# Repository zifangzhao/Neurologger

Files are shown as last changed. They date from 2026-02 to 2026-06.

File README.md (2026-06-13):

# WILD

**WILD** (Wireless, Interactive, Lightweight Datalogger) is an ultra-lightweight multimodal neurologger for long-term neural and behavioral recording in freely behaving animals. It combines local neural data logging, behavioral sensing, onboard processing, and responsive stimulation in a head-mounted platform designed for naturalistic and multi-animal experiments.

## Documentation

The documentation portal is built with MkDocs Material and is maintained through Markdown files in [`docs/`](docs/).

- [Getting Started](docs/getting-started/index.md)
- [Hardware](docs/hardware/index.md)
- [Software](docs/software/index.md)
- [Analysis](docs/analysis/index.md)
- [Community](docs/contributing.md)

## Platform Scope

- Local microSD electrophysiology recording with BLE-based control, synchronization, status, and low-bandwidth preview
- Closed-loop stimulation through embedded DSP and curated TinyML pipelines
- Current open-source 64-channel workflows, with Neuropixels-compatible and active-probe variants documented separately as research targets
- IMU, ultrasonic audio, camera, and digital event recording
- TinyML inference support through validated release-integrated models
- Long-term recording and multi-animal experiment workflows

## Repository Layout

| Path | Purpose |
| --- | --- |
| [`docs/`](docs/) | MkDocs documentation source |
| [Latest GitHub release](https://github.com/ayalab1/Neurologger/releases/latest) | Prebuilt device release images |
| [`Software/`](Software/) | WILD_console installers |
| [`Code/`](Code/) | MATLAB and Python analysis scripts |
| [`PCB/`](PCB/) | PCB fabrication and assembly files |
| [`3Dprint/`](3Dprint/) | Mechanical parts and CAD files |

## Local Documentation Build

```bash
pip install -r requirements.txt
mkdocs serve
```

The GitHub Pages workflow builds the site with:

```bash
mkdocs build --strict
```

## License

See [LICENSE](LICENSE).

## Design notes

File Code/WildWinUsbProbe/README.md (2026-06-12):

# WILD WinUSB Experiment

This folder is the host-side experiment package for moving the WILD camera preview path away from raw-disk MSC access and onto a WinUSB bulk stream.

## What Is In Here

- `Program.cs`
  - Console tool with:
    - `probe`
    - `paths`
    - `bench-winusb`
    - `bench-msc`
- `WILD_FS_Bridge_WinUSB.inf`
  - Local WinUSB binding package for `USB\VID_0483&PID_572A`
  - Registers the recovered interface GUID `{6C303587-B774-4A8B-8AFF-20557620207A}`
- `Install-WildWinUsbDriver.ps1`
  - Admin install helper for the local INF and a forced device restart
- `Register-WildWinUsbGuid.ps1`
  - Elevated helper that injects `DeviceInterfaceGUIDs` into the live device hardware key and restarts it
- `Reenumerate-WildDevice.ps1`
  - Elevated helper that removes the device and forces a fresh scan after the GUID injection
- `Recover-WildWinUsbGuid.ps1`
  - Read-only SWD helper that dumps the first 512 KB of flash and extracts the WinUSB identity markers

## Current Device Facts

- The shipped desktop app is still on the old MSC/raw-disk path.
  - Installed `WILD_console.exe` still contains `GetPhysicalDriveList`, `CE32_diskIO`, and volume lock/dismount strings.
- The currently attached board is already running a WinUSB firmware image.
  - USB identity: `VID_0483`, `PID_572A`
  - Product string from flash: `WILD USB FS Bridge`
  - Interface string from flash: `WinUSB Stream`
  - WinUSB interface GUID from flash:
    - `{6C303587-B774-4A8B-8AFF-20557620207A}`
- The firmware-side MS OS descriptor block in flash is populated with:
  - `MSFT100`
  - `WINUSB`
  - `DeviceInterfaceGUIDs`
  - the recovered GUID above

## Why The Probe Still Fails On This Machine

Windows currently exposes only the generic USB device interface:

- `\\?\USB#VID_0483&PID_572A#2004BF1A0800#{a5dcbf10-6530-11d2-901f-00c04fb951ed}`

Observed state:

- `winusb.inf` is bound to the device through `USB\MS_COMP_WINUSB`
- the recovered custom GUID is not present under `HKLM\SYSTEM\CurrentControlSet\Control\DeviceClasses`
- `WinUsb_Initialize` on the generic USB interface path fails with `ERROR_INVALID_HANDLE (6)`

So the board is on the WinUSB driver stack, but this host has not exposed an openable user-mode interface for the recovered GUID yet.

## What Was Tried On This Machine

1. Elevated install of `WILD_FS_Bridge_WinUSB.inf`
   - Windows rejected it because the package is unsigned.
2. Elevated write of `DeviceInterfaceGUIDs` directly into:
   - `HKLM\SYSTEM\CurrentControlSet\Enum\USB\VID_0483&PID_572A\2004BF1A0800`
3. Elevated `pnputil /restart-device`
4. Elevated `pnputil /remove-device` followed by `pnputil /scan-devices`

Result after every attempt:

- only the generic `{a5dcbf10-6530-11d2-901f-00c04fb951ed}` USB interface is published
- `WinUsb_Initialize` still fails with `ERROR_INVALID_HANDLE (6)`

The log files for those runs are stored next to the scripts:

- `install-driver.log`
- `register-guid.log`
- `reenumerate-device.log`

## Build

```powershell
dotnet build Code\WildWinUsbProbe\WildWinUsbProbe.csproj -c Release
```

## Probe The Current WinUSB State

```powershell
dotnet Code\WildWinUsbProbe\bin\Release\net8.0-windows\WildWinUsbProbe.dll probe
```

Print candidate interface paths only:

```powershell
dotnet Code\WildWinUsbProbe\bin\Release\net8.0-windows\WildWinUsbProbe.dll paths
```

## Benchmark The WinUSB Path

```powershell
dotnet Code\WildWinUsbProbe\bin\Release\net8.0-windows\WildWinUsbProbe.dll bench-winusb --seconds 5 --read-bytes 16384 --frame-bytes 163840
```

Defaults:

- instance id: `USB\VID_0483&PID_572A\2004BF1A0800`
- start request: `0x40`
- stop request: `0x41`
- status request: `0x42`
- equivalent frame size: `320 * 512 = 163840` bytes

## Benchmark The Legacy MSC Path

The old Python preview loop reads one fixed `163840` byte window from:

- offset `0x1000 * 512 = 0x200000`

Use the console benchmark the same way:

```powershell
dotnet Code\WildWinUsbProbe\bin\Release\net8.0-windows\WildWinUsbProbe.dll bench-msc --path \\.\PhysicalDrive3 --seconds 5
```

## Register The WinUSB Interface On This Host

The local INF is intended to give Windows a stable interface registration for the recovered GUID:

```powershell
powershell -ExecutionPolicy Bypass -File Code\WildWinUsbProbe\Install-WildWinUsbDriver.ps1
```

This requires an elevated shell. If Windows rejects the package because it is unsigned, use it as the template for a signed driver package in the real source tree.

## Recover The GUID Again From SWD

This requires:

- ST-LINK connected
- `STM32CubeProgrammer` installed
- read-only SWD access to the board

```powershell
powershell -ExecutionPolicy Bypass -File Code\WildWinUsbProbe\Recover-WildWinUsbGuid.ps1
```

## Measurement Goal

The intended experiment flow is:

1. Measure the old MSC path with `bench-msc` on an MSC firmware image.
2. Rebind the live WinUSB image with the local interface GUID.
3. Measure the WinUSB bulk path with `bench-winusb`.
4. Compare the equivalent frames per second from both runs.

If step 2 does not succeed on this machine, the remaining gap is host driver registration, not missing firmware-side WinUSB identity data.

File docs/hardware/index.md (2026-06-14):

# Hardware

Hardware documentation covers the WILD device architecture, board fabrication assets, mechanical assembly, power choices, and release-image compatibility for each supported device revision.

<div class="wild-grid two">
  <div class="wild-card">
    <h3>Device Overview</h3>
    <p>Core device specifications, supported modalities, local storage path, wireless control, and closed-loop output paths.</p>
  </div>
  <div class="wild-card">
    <h3>PCB</h3>
    <p>Board packages, fabrication outputs, assembly files, revision notes, and inspection points for manufactured boards.</p>
  </div>
  <div class="wild-card">
    <h3>Mechanical</h3>
    <p>Printable parts, baseplates, camera mounts, enclosure orientation, and fit checks for head-mounted assemblies.</p>
  </div>
  <div class="wild-card">
    <h3>Power</h3>
    <p>Battery and microSD guidance covering boot current, recording runtime, preview load, stimulation, and camera use.</p>
  </div>
  <div class="wild-card">
    <h3>Release Images</h3>
    <p>Validated WILD device images linked to compatible hardware revisions and experiment metadata.</p>
  </div>
</div>

## Hardware Asset Map

| Hardware area | Repository path |
| --- | --- |
| Datalogger PCB | [PCB/Datalogger](https://github.com/ayalab1/Neurologger/tree/main/PCB/Datalogger) |
| Opto module | [PCB/Optomodule](https://github.com/ayalab1/Neurologger/tree/main/PCB/Optomodule) |
| Camera unit | [PCB/CameraUnit](https://github.com/ayalab1/Neurologger/tree/main/PCB/CameraUnit) |
| Mechanical parts | [3Dprint](https://github.com/ayalab1/Neurologger/tree/main/3Dprint) |
| Battery table | [LipoBattery_selection.csv](https://github.com/ayalab1/Neurologger/blob/main/docs/LipoBattery_selection.csv) |
| Prebuilt device images | [Latest GitHub release](https://github.com/ayalab1/Neurologger/releases/latest) |

## Compatibility Record

Document the following for each supported WILD hardware build or dataset:

| Record | Why it matters |
| --- | --- |
| PCB or device revision | Distinguishes connector layout, sensor options, and supported release images. |
| Release tag and image filename | Ties behavior to a reproducible device image. |
| WILD_console version | Defines the export and control tool behavior used in the session. |
| SD card model | Affects boot reliability and long-session write stability. |
| Battery model | Affects boot margin, runtime, and peak-load behavior. |
| Enabled modalities | States whether the session used ephys, IMU, audio, video, stimulation, or external sync. |

## Bring-Up Checklist

Before the first recording on a newly assembled WILD device:

1. Confirm the intended release image and hardware revision match.
2. Confirm battery polarity and boot stability.
3. Confirm microSD insertion and basic discoverability.
4. Confirm BLE connection and synchronization state.
5. Run a short recording, export it, and verify the expected files before any animal session.

## Visual Asset Policy

Public hardware visuals are limited to real WILD device material: device photographs, CAD or EDA exports, microscope images, measured drawings, screenshots from project tools, or hand-authored diagrams derived from measured hardware. AI-generated device photographs or device-like renders are excluded from WILD hardware documentation.

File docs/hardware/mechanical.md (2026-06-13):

# Mechanical

Mechanical files are stored in the repository for baseplates, covers, and camera-related parts.

## Available Files

| Part | Repository path |
| --- | --- |
| Top cover | [WILD_TopCover.STL](https://github.com/ayalab1/Neurologger/blob/main/3Dprint/MouseCase/WILD_TopCover.STL) |
| Baseplate | [WILD_Baseplate.STL](https://github.com/ayalab1/Neurologger/blob/main/3Dprint/MouseCase/WILD_Baseplate.STL) |
| Camera baseplate | [WILD_Baseplate_Camera.STL](https://github.com/ayalab1/Neurologger/blob/main/3Dprint/MouseCase/WILD_Baseplate_Camera.STL) |
| Mouse-case CAD source | [Wild_Case.SLDPRT](https://github.com/ayalab1/Neurologger/blob/main/3Dprint/MouseCase/Wild_Case.SLDPRT) and [WILD_Case.f3d](https://github.com/ayalab1/Neurologger/blob/main/3Dprint/MouseCase/WILD_Case.f3d) |
| Cambridge NeuroTech probe assembly | [WILDAssemblyVertical.stp](https://github.com/ayalab1/Neurologger/blob/main/3Dprint/CambridgeNT_Probe/WILDAssemblyVertical.stp), [WILDAssemblyVertical.f3d](https://github.com/ayalab1/Neurologger/blob/main/3Dprint/CambridgeNT_Probe/WILDAssemblyVertical.f3d), and printable support parts in `3Dprint/CambridgeNT_Probe/` |

## Rendered Model Views

<div class="wild-grid two">
  <figure class="wild-image-frame">
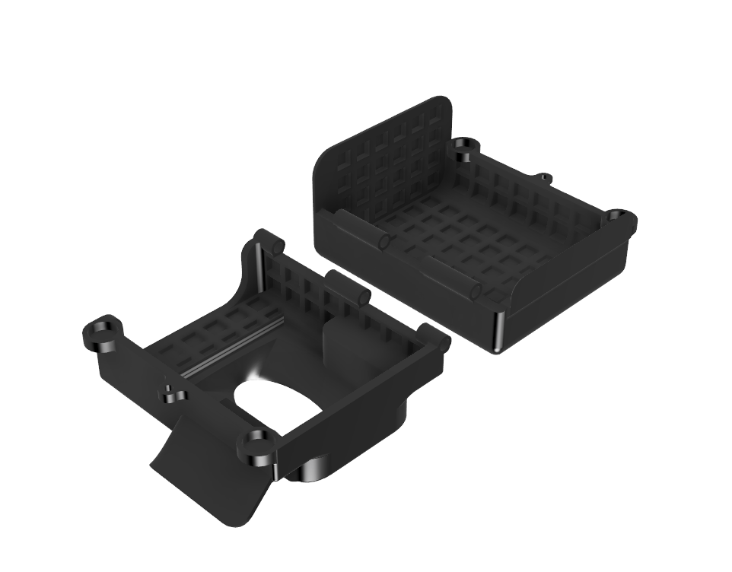
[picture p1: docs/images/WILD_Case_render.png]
Rendered WILD mouse case model with baseplate and cover
    
    <figcaption class="wild-caption">Mouse-case render showing the baseplate and cover geometry for device protection and mounting.</figcaption>
  </figure>
  <figure class="wild-image-frame">
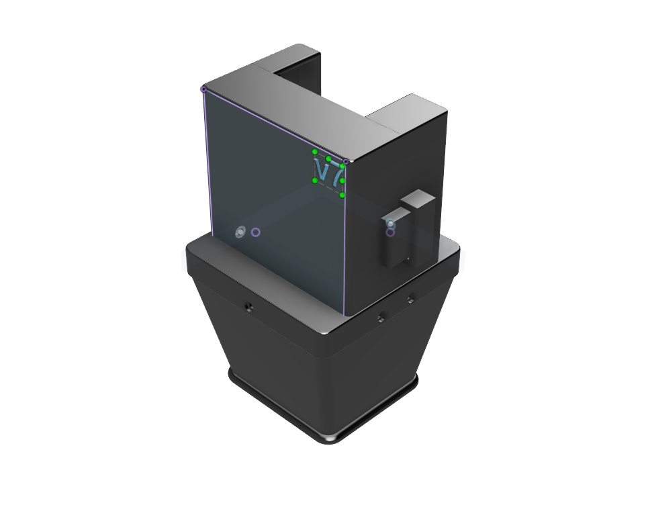
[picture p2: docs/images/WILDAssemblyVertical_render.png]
Rendered vertical WILD assembly for Cambridge NeuroTech probe workflow
    
    <figcaption class="wild-caption">Vertical assembly render for the Cambridge NeuroTech probe workflow, useful for checking model orientation and enclosure clearance.</figcaption>
  </figure>
</div>

## Design Considerations

- Keep cable strain relief and connector access visible in photos.
- Document orientation of the baseplate relative to probes, stimulation leads, and camera modules.
- Include printing material, layer height, support recommendations, and post-processing steps.
- Add animal-specific mounting notes only after local approval and protocol review.

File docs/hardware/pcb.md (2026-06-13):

# PCB

Board packages support ordering, assembly, and inspection for WILD hardware revisions.

## Fabrication Files

| Board | Files |
| --- | --- |
| Datalogger | [Gerbers, drill files, assembly files](https://github.com/ayalab1/Neurologger/tree/main/PCB/Datalogger) |
| Opto module | [Gerbers, drill files, assembly files](https://github.com/ayalab1/Neurologger/tree/main/PCB/Optomodule) |
| Camera unit | [Gerbers, drill files, assembly files](https://github.com/ayalab1/Neurologger/tree/main/PCB/CameraUnit) |

## Manufacturing Notes

- Review PCB stackup, impedance constraints, and connector orientation before ordering.
- Confirm component availability against the assembly files.
- Inspect the microSD socket, battery connector, BLE UART pins, sensor connectors, and stimulation output path after assembly.
- Keep manufacturing revisions tied to compatible release images.

## Assembly Checks

- Confirm top and bottom orientation against the board files.
- Inspect connectors, solder joints, and the microSD socket before power-up.
- Keep the PCB revision with the experiment metadata.
- Match each board revision to a compatible release image.

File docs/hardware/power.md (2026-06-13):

# Power

Power planning is central to WILD experiments because battery selection, microSD choice, recording mode, selected preview signals, stimulation, and camera use all affect runtime.

## Power Architecture

The WILD device conditions the selected battery through a converter and regulator chain before powering analog acquisition, digital control, and peripheral subsystems. Battery choice should therefore follow the validated hardware-revision guidance rather than a single nominal-voltage number.

Boot, microSD writes, camera use, stimulation, and live preview can create different peak-load conditions. Validate the complete experiment mode on the bench before using a battery in an animal session.

## Battery

The WILD device should use a battery approved for the specific hardware revision and experiment mode. Before mounting the device, confirm that the battery can boot the device without voltage sag, start recording, and sustain the planned sensors, preview state, stimulation, or camera load.

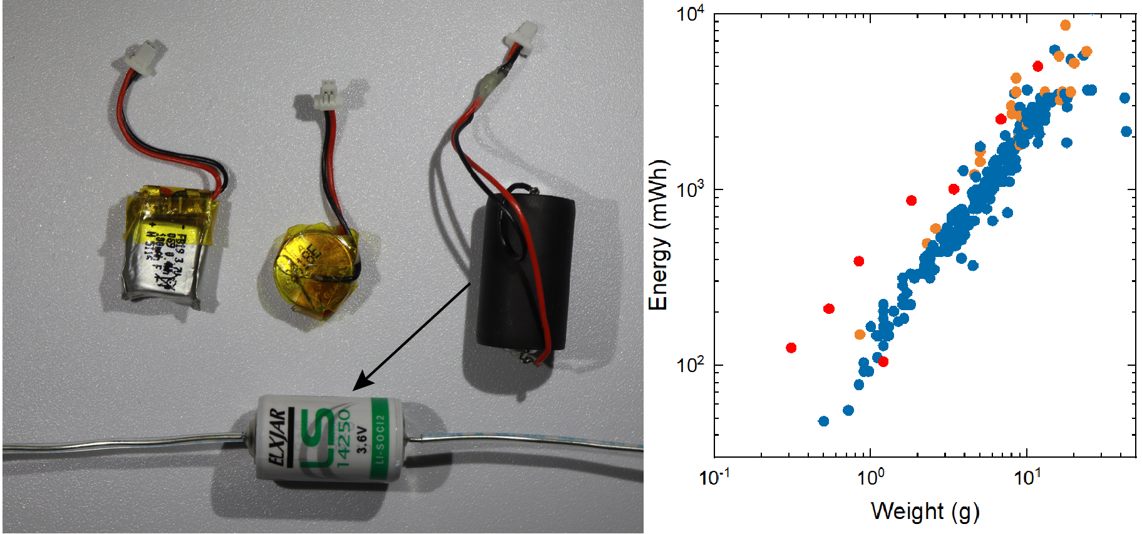
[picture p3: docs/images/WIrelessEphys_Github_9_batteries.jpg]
Battery examples


The [battery selection table](https://github.com/ayalab1/Neurologger/blob/main/docs/LipoBattery_selection.csv) provides baseline capacity and runtime-planning references.

## microSD Power

The microSD card is part of the power and reliability budget. Format cards with WILD_console before recording, and validate the selected card in the same sampling and modality mode planned for the experiment.

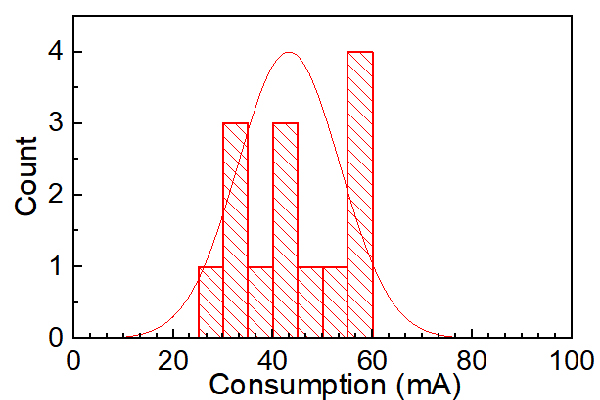
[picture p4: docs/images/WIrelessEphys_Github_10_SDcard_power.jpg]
microSD power comparison


## Runtime Reporting

Runtime depends on sampling rate, active modalities, preview state, stimulation use, microSD card model, battery capacity, and ambient conditions. When reporting a WILD recording mode, include:

- Release image.
- SD card model and format state.
- Battery model and capacity.
- Sampling rate and enabled modalities.
- Preview state.
- Stimulation or TinyML state, if used.
- Session environment, especially for outdoor or long-duration recordings.

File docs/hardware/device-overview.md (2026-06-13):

# Device Overview

The WILD device is a Wireless, Interactive, Lightweight Datalogger: an ultra-lightweight multimodal neurologger for freely behaving animals. The device combines local neural data logging, auxiliary sensing, onboard processing, BLE configuration and status, synchronization, and responsive stimulation.

The WILD device is not a BLE telemetry system. High-bandwidth neural data are recorded locally to microSD; wireless links are used for discovery, configuration, synchronization, status, low-bandwidth preview, and online control commands.

The device is best understood as a head-mounted acquisition and control unit. Neural acquisition, auxiliary sensing, embedded processing, microSD storage, external I/O, and optional stimulation are handled on the device; the host computer or controller supports setup, timing coordination, status review, selected preview, command delivery, and export.

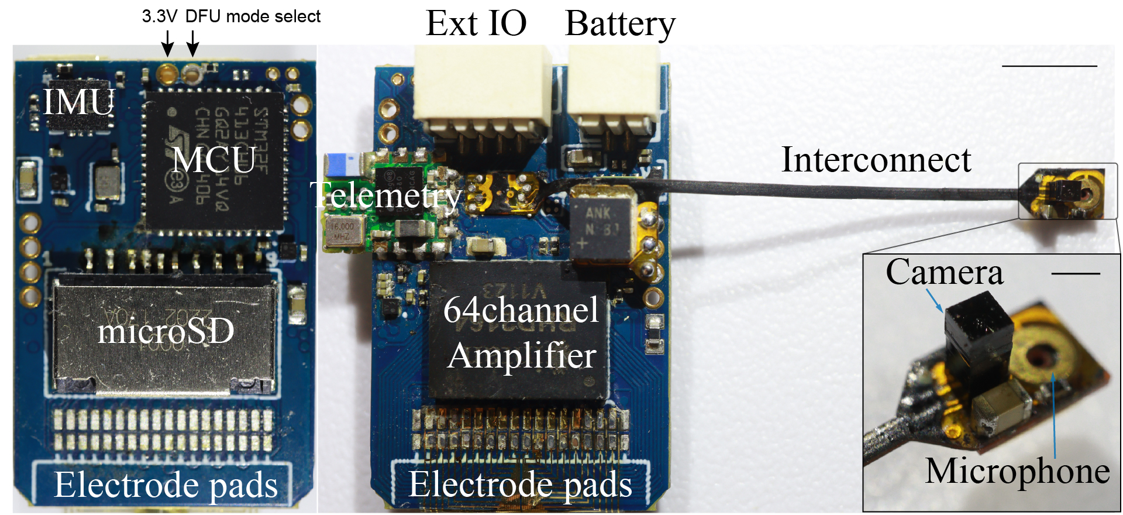
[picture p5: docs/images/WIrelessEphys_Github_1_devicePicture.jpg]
WILD device


## Functional Blocks

```mermaid
flowchart TB
  Probe[Neural probe] --> AFE[Analog front end]
  Sensors[IMU, audio, camera, digital inputs] --> MCU[MCU and embedded DSP]
  AFE --> MCU
  MCU --> SD[microSD storage]
  MCU --> BLE[BLE control, sync, status, preview]
  MCU --> ExtIO[External IO sync and control]
  MCU --> USB[USB setup and bench streaming]
  MCU --> Stim[Stimulation outputs]
  SD --> Analysis[MATLAB, Python, spike sorting]
```

## Device Interfaces

| Interface | Public documentation focus |
| --- | --- |
| Neural input | Standard 64-channel connector workflows and WILD flexible-probe workflows. |
| Local storage | Full-resolution neural, IMU, audio, camera, and event data are recorded to microSD. |
| Wireless control | BLE supports discovery, configuration, synchronization support, status checks, selected preview, and commands. |
| External I/O | Sync and control lines connect WILD devices with cameras, behavior systems, stimulation modules, and multi-device sessions. |
| Bench setup | USB and wired interfaces can support setup and validation workflows when high-bandwidth local monitoring is needed. |

### USB-GPIO Board

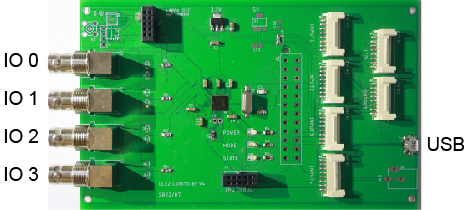
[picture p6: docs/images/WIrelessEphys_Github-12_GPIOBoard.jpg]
USB-GPIO board with IO0 to IO3 and USB interface labels


The USB-GPIO board exposes four external I/O lines and a USB connection for synchronization and validation workflows. Use it when checking camera triggers, behavioral-system events, stimulation-control lines, or multi-device timing before animal recordings.

## Current Public Scope

- The current open-source WILD device release is the 64-channel local-storage neurologger workflow.
- Higher-performance Neuropixels-compatible and active-SPI-probe workflows are separate research and variant targets.
- Multi-device experiments use explicit synchronization workflows rather than BLE timestamps alone.
- Mass is configuration-dependent; report device-only mass, probe or module mass, battery mass, and complete implant mass separately.

## Core Specifications

| Category | Current WILD specification |
| --- | --- |
| Neural channels | 64 |
| Device mass | Approximately 1.5 g for the logger board, configuration-dependent |
| Board dimensions | 23.3 x 15.7 mm |
| MCU | Cortex-M4 class MCU for acquisition, embedded DSP, TinyML scheduling, and device control |
| Power input | Use release-specific approved battery options; internal rails are generated by a converter/regulator chain |
| Sampling rates | 1,250-20,000 Hz |
| ADC resolution | 16-bit electrophysiology and microphone data; 10-bit camera data |
| Storage | microSD, Class 10 or better; low-power endurance cards are preferred |
| Recommended cards | Samsung EVO older orange U1 generation or tested Lexar cards |
| BLE | Control link for discovery, synchronization support, status, selected preview, and low-bandwidth commands |
| IMU | BMX160, up to 500 Hz |
| USV microphone | SPH6611LR5H, approximately 1-80 kHz bandwidth |
| Camera | NanEye-C, 320 x 320 px, 16 FPS, 10-bit |
| Stimulation | Optional two-channel laser-diode stimulation module based on TPS6115x |

## Supported Modalities

- Local neural electrophysiology recording.
- Responsive closed-loop stimulation from onboard detection.
- IMU sensing and sensor fusion.
- Ultrasonic vocalization audio through ADC data.
- Head-mounted camera data through `misc.dat`.
- Digital input and synchronization signals.
- External I/O for synchronization, stimulation control, and integration with behavioral equipment.

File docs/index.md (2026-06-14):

---
hide:
  - navigation
  - toc
---

<section class="wild-hero">
  <div>
    <h1>A wireless modular platform for neuro-behavioral recording and closed-loop manipulation in small animals</h1>
    <p>The Wireless, Interactive, Lightweight Datalogger (WILD) device is an ultra-lightweight multimodal neurologger for local neural data logging, behavioral sensing, onboard processing, and responsive stimulation in freely behaving animals.</p>
    <div class="wild-actions">
      <a class="md-button md-button--primary" href="getting-started/">Get Started</a>
      <a class="md-button" href="hardware/">Hardware</a>
      <a class="md-button" href="software/">Software</a>
      <a class="md-button" href="https://github.com/ayalab1/Neurologger">GitHub</a>
    </div>
    <div class="wild-signal-row">
      <span>64-Channel electrophysiology</span>
      <span>Closed-loop DSP</span>
      <span>9-axis IMU</span>
      <span>USV audio</span>
      <span>Camera</span>
    </div>
  </div>
  <figure class="wild-hero-media">
    WILD wireless modular datalogger device
    <figcaption class="wild-caption">The WILD device integrates local neural recording, behavioral monitoring, real-time embedded processing, microSD storage, and wireless control for naturalistic systems neuroscience experiments.</figcaption>
  </figure>
</section>

<section class="wild-section">
  <div class="wild-grid two">
    <div class="wild-card">
      <h2>Current Public Workflow</h2>
      <p><strong>Stable public scope:</strong> 64-channel local-storage WILD workflow, WILD_console on Windows, validated release images, and post-processing through documented MATLAB and Python scripts.</p>
      <p><strong>Not the current public model:</strong> full-bandwidth BLE telemetry or arbitrary runtime AI-model upload.</p>
    </div>
    <div class="wild-card">
      <h2>Release Record</h2>
      <p>Use the <a href="https://github.com/ayalab1/Neurologger/releases/latest">latest GitHub release</a> and record the exact release tag, release image filename, hardware revision, WILD_console version, SD card, and battery in every experiment note.</p>
    </div>
  </div>

  <div class="wild-grid">
    <div class="wild-card">
      <h3>Run a first recording</h3>
      <p><a href="getting-started/hardware-setup/">Hardware Setup</a> -> <a href="getting-started/data-acquisition/">Data Acquisition</a> -> <a href="getting-started/data-analysis/">Data Analysis</a></p>
    </div>
    <div class="wild-card">
      <h3>Build hardware</h3>
      <p><a href="hardware/pcb/">PCB</a> -> <a href="hardware/mechanical/">Mechanical</a> -> <a href="hardware/power/">Power</a></p>
    </div>
    <div class="wild-card">
      <h3>Analyze data</h3>
      <p><a href="software/data-format/">Data Format</a> -> <a href="analysis/matlab/">MATLAB</a> -> <a href="analysis/python/">Python</a> -> <a href="analysis/spike-sorting/">Spike Sorting</a></p>
    </div>
    <div class="wild-card">
      <h3>Cite or reproduce a result</h3>
      <p><a href="publications/">Publications</a> -> release metadata -> reproducibility notes -> analysis script version</p>
    </div>
  </div>
</section>

<section class="wild-zoom-tour" aria-label="WILD device zoom tour">
  <div class="wild-zoom-stage" aria-live="polite">
    <h2 id="wild-zoom-title">Embedded control at the headstage</h2>
    <p id="wild-zoom-description">The MCU, IMU, and board-level control electronics sit close to the animal, reducing external cabling while keeping timing-sensitive acquisition local.</p>
    <figure class="wild-zoom-frame">
      Real WILD device with labeled functional regions
      <figcaption id="wild-zoom-label">MCU and IMU</figcaption>
    </figure>
  </div>

  <div class="wild-zoom-scroll" aria-hidden="true">

  </div>
</section>

<section class="wild-section">
  <h2>Key Features</h2>
  <p>The WILD device is built around local neural logging, responsive stimulation, embedded processing, multimodal sensing, and long-duration experiments.</p>
  <div class="wild-grid">
    <div class="wild-card">
      <h3>Local Neural Logging</h3>
      <p>High-bandwidth electrophysiology is recorded locally to microSD, while BLE supports setup, synchronization, status, and low-bandwidth preview.</p>
    </div>
    <div class="wild-card">
      <h3>Responsive Stimulation</h3>
      <p>Onboard biomarker detection and behavioral classification can trigger stimulation without requiring continuous wireless data streaming.</p>
    </div>
    <div class="wild-card">
      <h3>TinyML on Edge Devices</h3>
      <p>Curated models run on the MCU through validated release images with RAM, timing, and closed-loop latency reviewed before deployment.</p>
    </div>
    <div class="wild-card">
      <h3>Multimodal Sensing</h3>
      <p>Neural signals, IMU, auxiliary inputs, ultrasonic audio, camera, and digital events.</p>
    </div>
    <div class="wild-card">
      <h3>Long-term Recording</h3>
      <p>Local storage, low power operations, and robust export tools for naturalistic studies.</p>
    </div>
  </div>
</section>

<section class="wild-section">
  <h2>Device Specification Summary</h2>
  <p>Representative WILD device operating modes show how channel count, aggregate sample rate, sensing modules, and onboard processing affect power draw.</p>
  <div class="wild-spec-scroll" role="region" aria-label="WILD device operating mode specification summary" tabindex="0">
    <table class="wild-spec-table">
      <thead>
        <tr>
          <th>Power (mW)</th>
          <th>Channels</th>
          <th>Aggregate samples/s</th>
          <th>Mode</th>
          <th>Weight (g)</th>
          <th>Video</th>
          <th>Audio</th>
          <th>Motion sensor</th>
          <th>Processing</th>
        </tr>
      </thead>
      <tbody>
        <tr><td>0.11</td><td>0</td><td>0</td><td>Sleep</td><td>1.48</td><td>-</td><td>-</td><td>-</td><td>-</td></tr>
        <tr><td>24.42</td><td>8</td><td>4 x 10^4</td><td>Ephys, IMU</td><td>1.48</td><td>-</td><td>-</td><td>Accelerometer, gyroscope, magnetometer</td><td>Spectral power, TinyML</td></tr>
        <tr><td>194.04</td><td>64</td><td>2.6 x 10^6</td><td>Ephys, IMU</td><td>1.48</td><td>-</td><td>-</td><td>Accelerometer, gyroscope, magnetometer</td><td>Spectral power, TinyML</td></tr>
        <tr><td>208.67</td><td>64</td><td>2.92 x 10^6</td><td>Ephys, IMU, audio</td><td>1.48</td><td>-</td><td>160 kHz</td><td>Accelerometer, gyroscope, magnetometer</td><td>Spectral power, TinyML</td></tr>
        <tr><td>245.28</td><td>64</td><td>5.48 x 10^6</td><td>Ephys, IMU, audio, video</td><td>1.48</td><td>320 x 320 px, 16 Hz</td><td>160 kHz</td><td>Accelerometer, gyroscope, magnetometer</td><td>Spectral power, TinyML</td></tr>
      </tbody>
    </table>
  </div>
  <p class="wild-table-note">Values summarize measured or configured device operating modes. Report the exact hardware revision, release image, battery, SD card, enabled modules, and whether aggregate samples/s is summed across recorded streams when comparing runtime across experiments.</p>
</section>

<section class="wild-section">
  <h2>System Overview</h2>
  <p>A typical session moves from the animal-mounted WILD device to local storage, synchronization, and offline analysis.</p>
  <div class="wild-system-panels">
    <div class="wild-flow wild-flow-vertical" aria-label="WILD system overview">
      <div>Animal</div>
      <div>Device</div>
      <div>Sensors</div>
      <div>Storage</div>
      <div>Synchronization</div>
      <div>Analysis</div>
    </div>
    <figure class="wild-image-frame wild-system-figure">
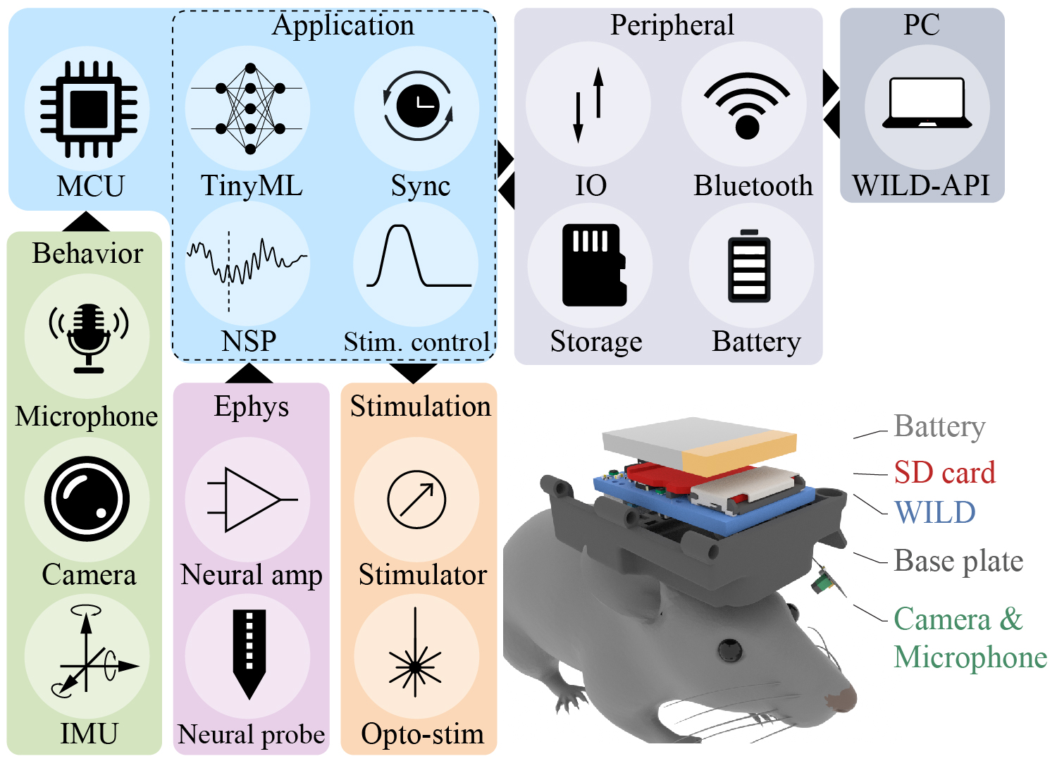
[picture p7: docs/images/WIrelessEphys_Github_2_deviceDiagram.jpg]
WILD system diagram
      
    </figure>
  </div>
</section>

<section class="wild-section">
  <h2>Research Highlights</h2>
  <div class="wild-grid">
    <div class="wild-card">
      <h3>Outdoor recordings</h3>
      <p>Local storage, low-power modes, and wireless control support recordings in large naturalistic environments where tethering is impractical.</p>
    </div>
    <div class="wild-card">
      <h3>Multi-animal experiments</h3>
      <p>Wired sync, BLE calibration, and clock correction workflows coordinate multiple WILD devices and external systems.</p>
    </div>
    <div class="wild-card">
      <h3>Ripple detection</h3>
      <p>DSP filters include ripple-band detection for closed-loop hippocampal experiments.</p>
    </div>
    <div class="wild-card">
      <h3>Theta phase stimulation</h3>
      <p>Hilbert and filter modes support phase-aware online control designs.</p>
    </div>
    <div class="wild-card">
      <h3>Naturalistic behavior</h3>
      <p>IMU, video, USV, and neural data support studies of social interaction, outdoor navigation, and other freely expressed behaviors.</p>
    </div>
    <div class="wild-card">
      <h3>Open hardware iteration</h3>
      <p>The repository contains WILD device hardware files, validated release assets, WILD_console installers, and analysis scripts.</p>
    </div>
  </div>
</section>

<section class="wild-section wild-quickstart">
  <h2>Quick Start</h2>
  <div class="wild-grid two">
    <div class="wild-card wild-step">
      <h3>Hardware setup</h3>
      <p>Connector, battery-polarity, microSD, probe-cabling, sensor-cabling, and release-image checks come before the first recording.</p>
    </div>
    <div class="wild-card wild-step">
      <h3>Data acquisition</h3>
      <p>WILD_console handles BLE connection, synchronization, recording configuration, closed-loop settings, and local logging startup.</p>
    </div>
    <div class="wild-card wild-step">
      <h3>Data analysis</h3>
      <p>Exported recordings are converted into Intan-style files, IMU and camera outputs, and spike-sorting inputs.</p>
    </div>
  </div>
  <p class="wild-table-note">Recommended first success target: complete a short bench recording, export the folder, confirm `amplifier.dat`, `analogin.dat`, `time.dat`, `info.rhd`, and `CE_params.bin`, then open the result with the documented MATLAB or Python workflow.</p>
</section>

<section class="wild-section">
  <h2>Publications and Citation</h2>
  <div class="wild-grid two">
    <div class="wild-card">
      <h3>Platform manuscript</h3>
      <p>The WILD platform manuscript is currently under review.</p>
    </div>
    <div class="wild-card">
      <h3>Repository and release versions</h3>
      <p>Report the hardware revision, release image, WILD_console version, and analysis scripts used for each dataset.</p>
    </div>
  </div>

```bibtex
@article{zhao_wild_neurologger,
  title        = {A wireless modular platform for neuro-behavioral recording and closed-loop manipulation in small animals},
  author       = {Zhao, Zifang and Chang, Hongyu and Paudel, Praveen and Park, Jaehyo and Liu, Can and Aurelio, Maria Q. and Oliva, Azahara and Fernandez-Ruiz, Antonio},
  year         = {2026},
  note         = {Under review}
}
```
</section>

<section class="wild-section">
  <h2>Community</h2>
  <div class="wild-grid">
    <div class="wild-card">
      <h3>GitHub</h3>
      <p><a href="https://github.com/ayalab1/Neurologger">Browse hardware files, release images, WILD_console installers, and analysis scripts.</a></p>
    </div>
    <div class="wild-card">
      <h3>Issues and Pull Requests</h3>
      <p>Use GitHub issues for reproducible bugs or documentation gaps, and pull requests for tested fixes, examples, and compatibility updates.</p>
    </div>
    <div class="wild-card">
      <h3>Contributing</h3>
      <p><a href="contributing/">Issues and pull requests are appropriate for hardware notes, analysis examples, compatibility reports, and documentation improvements.</a></p>
    </div>
  </div>
</section>

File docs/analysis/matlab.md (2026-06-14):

# MATLAB

MATLAB scripts currently provide the main preprocessing path for WILD recordings.

## Scripts

| Script | Purpose |
| --- | --- |
| [`WILD_PreProcess.m`](https://github.com/ayalab1/Neurologger/blob/main/Code/WILD_PreProcess.m) | Generate corrected headers, timing files, and event outputs. |
| [`WILD_PreProcessFolder.m`](https://github.com/ayalab1/Neurologger/blob/main/Code/WILD_PreProcessFolder.m) | Process multiple recordings. |
| [`WILD_ReadHeader.m`](https://github.com/ayalab1/Neurologger/blob/main/Code/WILD_ReadHeader.m) | Read WILD parameter headers. |
| [`WILD_processIMU.m`](https://github.com/ayalab1/Neurologger/blob/main/Code/WILD_processIMU.m) | Process IMU data. |
| [`WILD_scaleIMU.m`](https://github.com/ayalab1/Neurologger/blob/main/Code/WILD_scaleIMU.m) | Scale IMU signals. |
| [`WILD_genIntanHeader.m`](https://github.com/ayalab1/Neurologger/blob/main/Code/WILD_genIntanHeader.m) | Generate Intan-compatible header output. |

## Minimal Workflow

```matlab
cd("C:\code\github\Neurologger\Code");
recording_path = "C:\WILD\example_recording";
WILD_PreProcess(fullfile(recording_path, "amplifier.dat"));
WILD_processIMU(fullfile(recording_path, "analogin.dat"), 100);
```

Adjust paths and sampling assumptions for your recording mode.

## Expected Folder Layout

**Input**

```text
example_recording/
  amplifier.dat
  analogin.dat
  CE_params.bin
  adc.dat           # optional
  misc.dat          # optional
```

**Outputs generated by the public MATLAB path**

```text
example_recording/
  time.dat
  info.rhd
  IMU.mat
  device_event.d01.evt   # if digital events are present
  device_event.s01.evt   # if stimulation-related event files are generated
```

## Known-Good First Pass

1. Run `WILD_PreProcess` on `amplifier.dat`.
2. Confirm that `time.dat` and `info.rhd` appear.
3. Run `WILD_processIMU` on `analogin.dat`.
4. Confirm that `IMU.mat` is generated.
5. Keep the raw export unchanged and write downstream results into a separate analysis copy when reprocessing.

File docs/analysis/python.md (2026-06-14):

# Python

Python utilities cover camera decoding, audio handling, GPIO logging, and validation after SD-card export.

## Scripts

| Script | Purpose |
| --- | --- |
| [`WILD_VideoDecodewAudio.py`](https://github.com/ayalab1/Neurologger/blob/main/Code/WILD_VideoDecodewAudio.py) | Decode camera data with audio handling. |
| [`WILD_VideoDecodewAudio_v2.py`](https://github.com/ayalab1/Neurologger/blob/main/Code/WILD_VideoDecodewAudio_v2.py) | Alternative video decode pipeline. |
| [`WILD_VideoDecodewAudio_folder.py`](https://github.com/ayalab1/Neurologger/blob/main/Code/WILD_VideoDecodewAudio_folder.py) | Batch folder processing. |
| [`WILD_GPIO_Logger.py`](https://github.com/ayalab1/Neurologger/blob/main/Code/WILD_GPIO_Logger.py) | GPIO logging utility. |

## Typical Use

- Decode camera or audio files after exporting a recording folder.
- Batch-process multiple recording folders with the folder variants.
- Log GPIO or serial events during synchronization validation.
- Keep generated media and logs separate from the raw SD export.

## Interactive Commands

Run the Python tools from the repository `Code` folder:

```powershell
cd C:\code\github\Neurologger\Code
python .\WILD_VideoDecodewAudio.py
python .\WILD_VideoDecodewAudio_folder.py
python .\WILD_GPIO_Logger.py
```

- `WILD_VideoDecodewAudio.py` opens a file picker for one `misc.dat` recording and expects the matching `adc.dat` file when audio is present.
- `WILD_VideoDecodewAudio_folder.py` opens a folder picker and recursively processes `misc.dat` files below that root.
- `WILD_GPIO_Logger.py` prompts for a COM port and output folder, then writes a timestamped text log.

## Expected Outputs

```text
example_recording/
  misc.dat
  adc.dat
  adc.wav
  adc.mp3
  misc.mp4
  misc_wAudio.mp4
```

Output names depend on the script path and whether audio is present, but the public decoder workflow writes reviewable media next to the source export by default.

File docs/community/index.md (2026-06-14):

# Community

Community pages collect citation guidance, contribution rules, and support expectations for the public WILD workflow.

## Start Here

<div class="wild-grid two">
  <div class="wild-card">
    <h3>Publications</h3>
    <p>Use the repository citation guidance until the WILD manuscript has a final public citation.</p>
  </div>
  <div class="wild-card">
    <h3>Contributing</h3>
    <p>Report tested hardware revision, release image, software version, and validation notes with every documentation or compatibility update.</p>
  </div>
  <div class="wild-card">
    <h3>Support Path</h3>
    <p>Use GitHub issues and pull requests for reproducible bugs, documentation problems, compatibility reports, and analysis examples.</p>
  </div>
  <div class="wild-card">
    <h3>Visual Policy</h3>
    <p>Public device figures must come from real hardware, CAD, PCB, microscope, or hand-authored source-derived diagrams. AI-generated device imagery is excluded.</p>
  </div>
</div>

## Recommended Metadata for Public Reports

When sharing a method, bug report, example dataset, or compatibility note, include:

- Hardware revision.
- Release image or release tag.
- WILD_console version.
- SD card model.
- Battery model.
- Recording mode and sampling configuration.
- Whether audio, video, IMU, stimulation, or external sync were enabled.

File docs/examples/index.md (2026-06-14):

# Examples

These example workflows summarize common WILD device use cases and the metadata needed to make each experiment reproducible.

## Workflow Index

| Example | Scope | Expected validation |
| --- | --- |
| Basic neural recording | Battery, SD format, BLE connect, recording, export, preprocessing. | `amplifier.dat`, `analogin.dat`, `time.dat`, `info.rhd`, `CE_params.bin`. |
| Closed-loop ripple detection | Filter setup, thresholding, stimulation configuration, validation waveform. | Event files, threshold traces, and stimulation timing review. |
| Theta phase stimulation | Hilbert mode setup, phase logic, stimulation timing, event export. | Phase-locked trigger timing and stimulation event checks. |
| Multi-animal synchronization | Multiple WILD_console instances, start timing, sync line, analysis alignment. | Matched durations, stable offsets, and retained sync events. |
| Outdoor recording | Power planning, SD choice, wireless checks, data integrity checks. | Complete export, no unexpected truncation, and logged power configuration. |
| Camera plus IMU | Camera decode, IMU processing, and behavioral alignment. | Reviewable video output and generated `IMU.mat`. |

## Required Metadata

For each public dataset or protocol, record:

- Goal.
- Hardware revision.
- Release image.
- Software version.
- Required accessories.
- Step-by-step protocol.
- Expected outputs.
- Troubleshooting notes.
- Example data or a small validation file.

## Priority for Expanded Protocol Pages

The highest-value example pages to expand next are:

1. Basic neural recording.
2. Multi-animal synchronization.
3. Closed-loop ripple detection.

These three paths cover the first successful dry run, cross-device timing, and one validated responsive-control workflow.

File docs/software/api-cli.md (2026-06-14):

# Programmatic Workflows

WILD_console and the listed scripts form the supported public interface for acquisition, export, post-processing, and validation.

WILD_console handles BLE discovery, synchronization, configuration, selected preview, and SD-card export. Full-resolution recordings are recovered from local storage rather than streamed continuously over BLE.

An iOS-based WILD controller app is in development for wireless device control and is expected to provide more consistent BLE performance than typical PC BLE adapters. The current stable public export and post-processing workflow remains WILD_console plus the documented MATLAB and Python scripts.

!!! warning "No stable SDK yet"
    The supported public programmable surface is WILD_console plus the documented repository scripts. The project does not currently document a stable general-purpose SDK with a versioned command contract.

## Current Support

| Area | Current operation style | Purpose |
| --- | --- | --- |
| Acquisition | WILD_console | BLE discovery, connection, synchronization, recording setup, selected live preview, closed-loop configuration, and SD-card export. |
| Wireless control | iOS controller app, in development | BLE discovery, connection, synchronization support, status checks, and low-bandwidth commands. |
| Post-processing | MATLAB scripts | Header generation, timing correction, event export, IMU processing, and Intan-compatible output preparation. |
| Camera/audio decoding | Python scripts | Decode `misc.dat` and related audio data into reviewable media outputs. |
| Batch processing | Python and MATLAB scripts | Process folders of recordings after SD export. |
| GPIO logging | Python utility | Log serial/GPIO event data during validation or synchronization tests. |
| Release and model tracking | Release metadata workflow | Record release image, AI model identity, and tool version for reproducibility. |

## Supported Scripted Operations

The current public API surface is organized around these operations:

- Export recording folders from WILD_console.
- Generate corrected `info.rhd` and `time.dat` outputs.
- Convert raw WILD camera/audio data into media files.
- Process IMU channels into calibrated signals.
- Batch-process recording folders.
- Log GPIO or serial synchronization events.
- Preserve software, release-image, and model versions in experiment notes.

## Device Operation Categories

WILD_console and controller workflows expose device operations at a task level. Public documentation should describe these operations by purpose rather than by low-level command ID.

| Category | Typical operations |
| --- | --- |
| Recording control | Set recording parameters, start local recording, stop local recording, and confirm recording state. |
| Preview control | Start or stop selected-channel preview and choose preview channels without treating BLE as the full-resolution data path. |
| DSP and TinyML setup | Load curated DSP or model parameters from a validated release image and record the selected configuration in metadata. |
| Stimulation control | Configure stimulation intensity, thresholds, timing, and manual test triggers when the hardware revision supports stimulation. |
| Time and synchronization | Check the connection, coordinate PC-device time, set device time, and retain external I/O events for experiment-level alignment. |
| Device status | Read parameters, battery state, available storage, device identity, and release-image metadata. |
| Power state | Request sleep or reset only as part of the documented maintenance or field-session workflow. |
| External I/O | Route GPIO and synchronization signals to cameras, behavioral systems, stimulation modules, or additional WILD devices. |

## Tool Metadata

For reproducible use, record the following metadata with tool outputs and example datasets:

- Tool name and version.
- Required operating system and dependencies.
- Input folder or file layout.
- Command or launch procedure used.
- Output files and naming convention.
- Expected runtime and memory requirements.
- Failure modes and troubleshooting notes.
- Validation file or representative dataset, when available.

## SDK Status

WILD_console operations and documented processing scripts are the supported public surface. Script internals remain implementation details unless a workflow is explicitly documented.

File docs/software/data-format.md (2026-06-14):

# Data Format

Each WILD device recording session exports a folder with neural data, auxiliary signals, metadata, and optional camera or audio files.

## Files

| File | Verified public handling | Notes |
| --- | --- |
| `amplifier.dat` | Read by `WILD_PreProcess.m` as channel-interleaved 16-bit neural data. | Sample count is computed as `file_bytes / 2 / Nch`, with `Nch` read from `CE_params.bin`. |
| `analogin.dat` | Used as the auxiliary stream for digital inputs, IMU, and timing-related channels. | Public MATLAB scripts read this stream as 16 channels at 1250 Hz for preprocessing and IMU extraction. |
| `digitalin.dat` | Optional digital-input export artifact. | Not every workflow generates a separate file; public trigger generation currently derives digital events from `analogin.dat`. |
| `adc.dat` | ADC or audio stream used by microphone workflows. | Public Python decode scripts read this file as `uint16` mono audio and generate `.wav` or `.mp3` outputs. |
| `misc.dat` | Raw camera payload stream. | Public Python decode scripts convert this file into reviewable video outputs. |
| `time.dat` | Generated sample-index timeline. | Public MATLAB preprocessing writes `0:(Nsamples-1)` as `int32`. |
| `info.rhd` | Intan-compatible metadata header. | Generated from `CE_params.bin` by `WILD_genIntanHeader.m`. |
| `CE_params.bin` | WILD parameter binary for system and DSP settings. | The public docs refer to this as the WILD parameter binary; MATLAB tools use the filename `CE_params.bin`. |

## Export Decoding

The WILD device records compact local streams on its microSD card. During the current SD-card download workflow, WILD_console decodes the on-device recording into analysis-facing files: neural samples are written to `amplifier.dat`, auxiliary and timing words to `analogin.dat`, ADC or audio streams to `adc.dat`, camera payloads to `misc.dat`, and session parameters to the WILD parameter binary.

The exported folder is therefore the decoded public data interface. Raw device storage blocks are not the expected analysis input; downstream MATLAB and Python tools operate on the downloaded files and generate derived outputs such as `info.rhd`, `time.dat`, event files, media files, IMU outputs, and spike-sorting inputs.

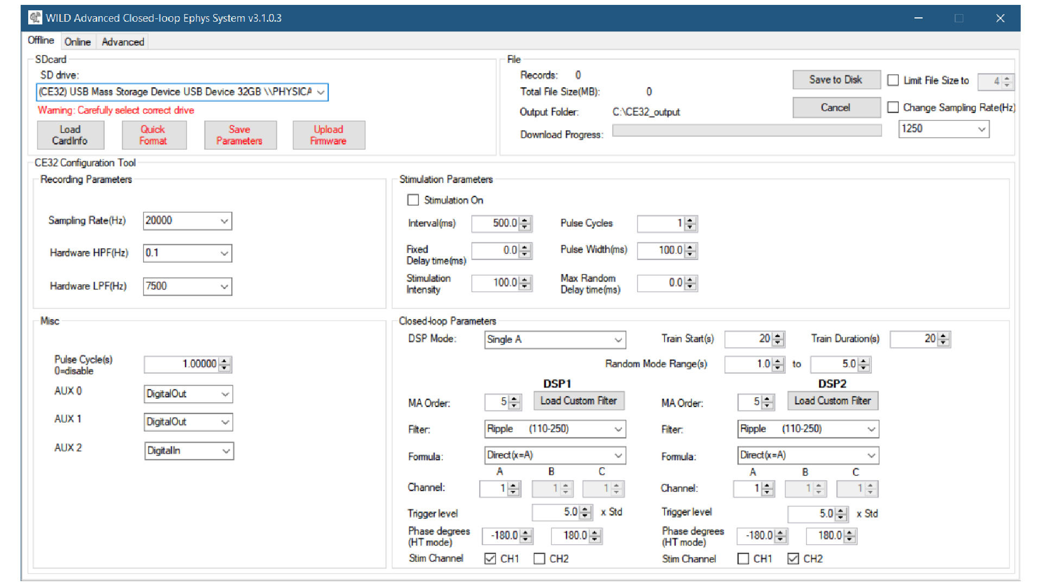
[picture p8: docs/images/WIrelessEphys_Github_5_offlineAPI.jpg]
WILD_console runtime screenshot of the offline export workflow


## Time Synchronization

The WILD device keeps high-bandwidth recordings local while WILD_console provides PC-device coordination over BLE. At connection and recording setup, the console synchronizes device state with the PC session and records timing context with the exported dataset.

Timing metadata should be interpreted as a layered system: device sample counts provide the primary sample timeline, PC-device timing coordination supports session-level alignment, and external I/O or digital events provide the most direct alignment path for external cameras, behavior systems, stimulation hardware, and multi-device sessions.

`time.dat` stores the sample-index timeline used by Intan-style workflows, while the WILD parameter binary preserves device-side recording time, hardware version, release image identity, sampling configuration, and DSP settings. External sync lines and digital inputs in `analogin.dat` or generated event files should be retained with the export whenever the experiment depends on cross-device or behavior alignment.

PC-device time synchronization is useful for session organization, export metadata, and cross-device coordination. It should not be treated as a substitute for hardware sync or digital event channels when the analysis requires high-precision alignment.

## Verified Script Assumptions

The following public assumptions are visible in the repository scripts and should be treated as the current documented behavior unless a release note states otherwise:

- `WILD_PreProcess.m` reads `amplifier.dat` as 16-bit neural samples and uses `CE_params.bin` to determine channel count and sampling rate.
- `time.dat` is written as a monotonically increasing `int32` sample index.
- `WILD_processIMU.m` reads channels `2:10` from `analogin.dat`, assumes a 1250 Hz source rate, and writes `IMU.mat` after resampling to 100 Hz by default.
- `WILD_PreProcess.m` reads channel `1` of `analogin.dat` as a `uint16` digital bitfield and generates `device_event.*.evt` files from its bit transitions.
- `WILD_VideoDecodewAudio.py` reads `adc.dat` as `uint16` audio, converts it to signed audio outputs, and assumes a 160 kHz audio path.
- `WILD_VideoDecodewAudio.py` reads `misc.dat` in `320 * 500` byte frame blocks and writes 320 x 320, 16 Hz decoded video outputs.

Where a file layout depends on a specific release image or modality, report the exact release tag and mode together with the dataset. Do not assume that every export contains every optional modality file.

## Multi-Device and Behavior Alignment

For multi-logger sessions, keep the raw export folder for each device and store merge or sync-estimation outputs alongside the derived files. Useful validation checks include matched `amplifier.dat` duration and file size, stable estimated sample offsets, continuous external TTL or digital events, and no unexpected gaps in camera frames.

Behavior datasets should state whether video, UWB, IMU, and ephys streams are expressed on corrected timestamps. Camera calibration, coordinate transforms, identity curation, and delay correction are part of the dataset metadata, especially for outdoor multi-animal work.

When a behavior pipeline produces files such as `behavior_all.mat`, document whether fields are aligned to corrected timestamps such as `timestamps_corrected` and which correction was used. Post-hoc delay estimation or time warping can help evaluate a session, but it should not replace acquisition-side sync validation.

## Intan-Compatible Layout

WILD exports are arranged to be familiar to users of Intan-style recording folders while preserving WILD-specific metadata for sensors, DSP, stimulation, and camera workflows.

## Best Practice

Keep three folders per experiment:

1. Raw SD export.
2. Converted analysis copy.
3. Downstream results from spike sorting, behavior alignment, or machine-learning analysis.

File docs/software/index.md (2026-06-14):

# Software

Software documentation covers how to connect to the WILD device, configure recordings in WILD_console, export data from the device microSD card, and process recordings for analysis.

## Software Components

<div class="wild-grid two">
  <div class="wild-card">
    <h3>WILD_console</h3>
    <p>Windows GUI for connecting to the WILD device over BLE, synchronizing the session, setting up recordings, previewing selected signals, configuring closed-loop behavior, and exporting SD-card data.</p>
  </div>
  <div class="wild-card">
    <h3>iOS controller</h3>
    <p>In-development app for WILD device discovery, BLE connection, synchronization support, status checks, and low-bandwidth control, with more consistent BLE performance expected than typical PC adapters.</p>
  </div>
  <div class="wild-card">
    <h3>Artificial Intelligence</h3>
    <p>Curated embedded models for validated closed-loop releases, with generic model loading not yet part of the stable workflow.</p>
  </div>
  <div class="wild-card">
    <h3>Programmatic workflows</h3>
    <p>Documented operations for data export, batch post-processing, video/audio decoding, GPIO logging, and validation utilities.</p>
  </div>
  <div class="wild-card">
    <h3>Analysis scripts</h3>
    <p>MATLAB and Python scripts for headers, timing, IMU processing, video decoding, and downstream analysis.</p>
  </div>
</div>

## Install

Download WILD_console from the [latest GitHub release](https://github.com/ayalab1/Neurologger/releases/latest). The link always opens the newest published WILD release.

## Public Workflow Boundary

The current public software path is:

1. Connect and record with WILD_console.
2. Export from the device microSD card.
3. Run documented MATLAB or Python post-processing.

The public documentation does not treat BLE as a continuous high-bandwidth acquisition path, and it does not promise a stable general-purpose SDK yet.

## Wireless Control

WILD_console remains the stable public control and export workflow. The iOS-based controller app is being developed as a lighter wireless-control path for BLE discovery, connection, synchronization support, status checks, and low-bandwidth commands. The iOS workflow is expected to perform better than PC BLE in many setups because it avoids variability across Windows Bluetooth adapters and drivers.

Full-resolution WILD recordings remain local to the device microSD card and are exported after the session.

## Requirements

- Windows 10 or later.
- .NET Framework 4.8 for the current GUI.
- Bluetooth 4.0 or later.
- Administrator privileges for some SD formatting workflows.

## Optional Runtime Files

- `dll_upfirdn.dll` for resampling.
- WILD BLE backend DLL for BLE support in older installer layouts.
- `ffmpeg.exe` for some camera processing workflows.

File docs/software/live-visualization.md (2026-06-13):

# Live Visualization

WILD_console includes a real-time display for previewing selected neural and auxiliary signals during recording.

Live view supports selected previews, status checks, and closed-loop monitoring. Full-resolution recordings are written locally to the device microSD card.

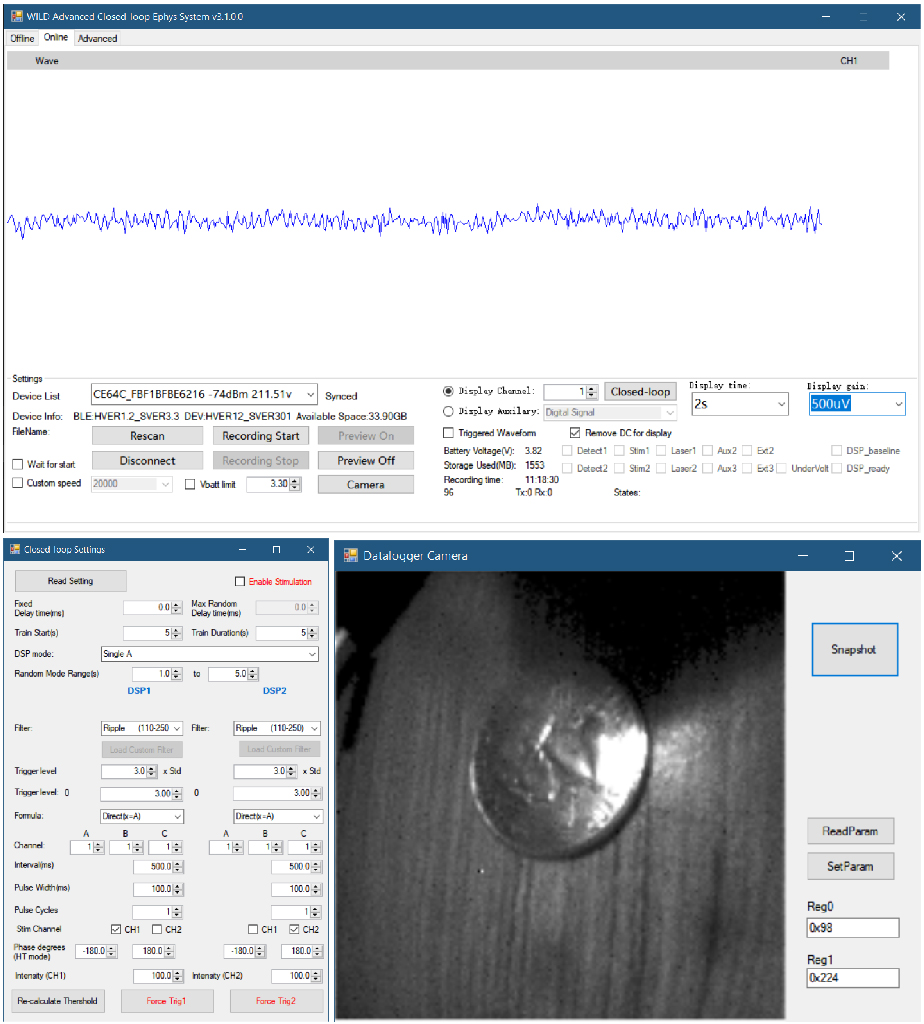
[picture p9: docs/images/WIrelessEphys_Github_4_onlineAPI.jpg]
WILD_console runtime screenshot with live preview and camera windows


## Camera Imaging Profile

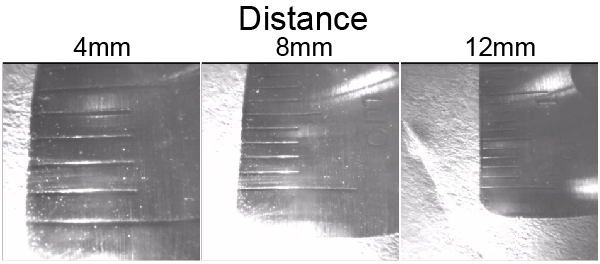
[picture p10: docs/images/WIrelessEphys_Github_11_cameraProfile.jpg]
Camera imaging profile at 4 mm, 8 mm, and 12 mm working distances


Use the camera imaging profile during bench setup to choose the working distance and focus range before mounting the camera module. Confirm the expected target distance with live preview before treating camera data as part of the experiment record.

## Display Controls

- Select neural preview channels.
- Select auxiliary signals from IMU and DSP outputs.
- Adjust display length.
- Adjust display gain.
- Show threshold overlays when closed-loop channels are selected.
- Monitor internal state, stimulation triggers, DSP state, and TinyML state messages.

## Power and Bandwidth

Live preview consumes device power and BLE bandwidth. Disable preview when the experiment prioritizes maximum runtime over live monitoring, and recover the full dataset from microSD after the session.

## Status Checks

- Confirm connection and TX/RX counters after BLE discovery.
- Confirm synchronization before starting a recording.
- Confirm recording state before handling the animal.
- Confirm export completion after removing the microSD card.
- Treat SD, BLE, low-battery, and release-image mismatch messages as session blockers until resolved.

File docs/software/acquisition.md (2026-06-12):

# Acquisition

The acquisition workflow starts by connecting to a WILD device in WILD_console and ends with exported recording folders from the device microSD card.

The WILD device records high-bandwidth neural and multimodal data locally. BLE is used for discovery, synchronization, configuration, status, selected preview, and control commands rather than continuous full-bandwidth data streaming.

WILD_console is the stable public control path today. An iOS-based WILD controller app is in development and is expected to provide more consistent BLE discovery, connection, and low-bandwidth control performance than typical PC BLE adapters. The iOS app is a controller path; full-resolution recordings remain stored on the device microSD card.

## Wireless Connection Model

The WILD device can be connected for discovery, synchronization support, parameter review, selected preview, and command delivery. After setup and timing coordination, local recording does not depend on continuous full-bandwidth wireless streaming because the device writes the full dataset to microSD.

For multi-device sessions, keep continuous BLE connected only for devices that need live preview or online commands. Devices that only need local logging can be configured and synchronized first, then managed with the planned start, stop, external I/O, and export workflow.

## Routine Operation Map

Most first-session work uses four button groups:

| Stage | Main UI area | Primary click |
| --- | --- | --- |
| Discover and connect | Online tab, Device List | <span class="wild-button-label">Rescan</span>, select the WILD device, then <span class="wild-button-label primary">Connect</span> |
| Start recording | Online tab, recording controls | <span class="wild-button-label primary">Recording Start</span> |
| Stop recording | Online tab, recording controls | <span class="wild-button-label">Recording Stop</span> |
| Export data | Offline tab, File panel | <span class="wild-button-label primary">Save to Disk</span> |

Closed-loop settings, camera controls, stimulation parameters, GPIO options, and advanced panels are optional experiment-specific controls. They are easier to configure after the basic connect-record-export path is working.

WILD_console runtime screenshot of the offline export workflow

## Typical Session

1. Start WILD_console.
2. Scan for the WILD device.
3. Connect over BLE.
4. Read current parameters and change experiment-specific settings only when needed.
5. Configure sampling, closed-loop, camera, stimulation, and GPIO options as needed.
6. Start local recording.
7. Monitor selected preview and state signals.
8. Stop recording.
9. Export data from the SD card.
10. Check duration, file size, representative channels, and sync markers before treating the session as complete.

## Multi-Device Sessions

Use one validated release set across all WILD devices. Assign the intended master/follower roles before the session, and keep the same wiring and start order used in the dry run.

For camera workflows, test the external TTL or camera sync path during a short continuous run and confirm that frames, event pulses, and recording files stay aligned before using the setup with animals.

After export, compare recording durations, file sizes, and sample counts across devices. A successful merge should show stable offsets across the recording; jumps, drifting offsets, or one logger ending early should be investigated before the data are treated as synchronized.

## Exported Files

The exported folder can include:

- `amplifier.dat`.
- `analogin.dat`.
- `digitalin.dat`.
- `adc.dat`.
- `misc.dat`.
- `supply.dat`.
- `time.dat`.
- `info.rhd`.
- WILD parameter binary.

See [Data Format](data-format.md) for field descriptions.

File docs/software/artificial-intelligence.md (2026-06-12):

# Artificial Intelligence

The WILD device supports onboard biomarker detection and behavioral classification for responsive stimulation.

Current WILD device releases are intentionally conservative: AI models are curated into validated release images and reviewed for RAM use, compute timing, sampling schedules, and closed-loop latency.

## Current Model Integration

Current AI support uses validated, experiment-specific models rather than arbitrary runtime uploads.

- Models are distributed as part of validated release images.
- RAM use is curated before deployment.
- Inference timing is checked against acquisition, storage, BLE, and DSP tasks.
- Model output is integrated with device state reporting and closed-loop logic.
- Release image and model identity are recorded with each experiment.

This approach keeps timing behavior predictable on resource-constrained embedded hardware.

## Generic Model Support

Generic model loading is not part of the stable public workflow yet. Current releases prioritize predictable timing, memory use, and closed-loop behavior.

Closed-loop model releases define:

- Accepted model format and quantization requirements.
- Maximum model size and tensor arena limits.
- Input and output tensor conventions.
- Inference scheduling relative to acquisition and DSP.
- Validation procedure before animal experiments.
- How model version, release image, and experiment metadata are recorded.

!!! warning "Deployment discipline"
    Embedded AI models are part of the validated device release. A model that passes desktop inference tests may still be unsafe for closed-loop use if RAM pressure or inference timing affects acquisition, storage, or stimulation behavior.

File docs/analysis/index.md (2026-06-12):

# Analysis

Use these pages to convert WILD exports into analysis-ready files, preserve timing metadata, and prepare datasets for MATLAB, Python, and spike-sorting workflows.

## Entry Points

<div class="wild-grid">
  <div class="wild-card">
    <h3>Python</h3>
    <p>Camera decoding, video/audio handling, GPIO logging, and pipeline integration scripts.</p>
  </div>
  <div class="wild-card">
    <h3>MATLAB</h3>
    <p>Header generation, preprocessing, IMU processing, and compatibility with existing lab scripts.</p>
  </div>
  <div class="wild-card">
    <h3>Spike Sorting</h3>
    <p>Export recordings into layouts usable by common spike sorting pipelines.</p>
  </div>
</div>

## Reproducibility Checklist

- Record release image filename.
- Record WILD_console version.
- Preserve raw export folder.
- Preserve the WILD parameter binary.
- Record probe, channel map, sampling rate, and stimulation configuration.
- Track post-processing script version or commit hash.

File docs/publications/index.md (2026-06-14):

# Publications

Publication notes collect the current WILD citation status and the release metadata needed for reproducible methods reporting.

## Platform Manuscript

The WILD platform manuscript is currently under review. Cite the manuscript once the final public citation is available. For repository-based methods descriptions, include the WILD hardware revision, release image, WILD_console version, and analysis-script version used in the work.

```bibtex
@article{zhao_wild_neurologger,
  title        = {A wireless modular platform for neuro-behavioral recording and closed-loop manipulation in small animals},
  author       = {Zhao, Zifang and Chang, Hongyu and Paudel, Praveen and Park, Jaehyo and Liu, Can and Aurelio, Maria Q. and Oliva, Azahara and Fernandez-Ruiz, Antonio},
  year         = {2026},
  note         = {Under review}
}
```

## Repository Citation

When citing a specific software or hardware release, include the GitHub repository URL and the exact release image, software version, and hardware revision used.

Repository: [https://github.com/ayalab1/Neurologger](https://github.com/ayalab1/Neurologger)

## How to Cite Before Publication

Until the platform manuscript has a final public citation, cite the repository and the exact release context used in the work:

- Repository URL.
- Release tag.
- Release image filename.
- Hardware revision.
- WILD_console version.
- Analysis script version or commit hash, when applicable.

The repository now includes a root `CITATION.cff` file for software-style citation metadata.

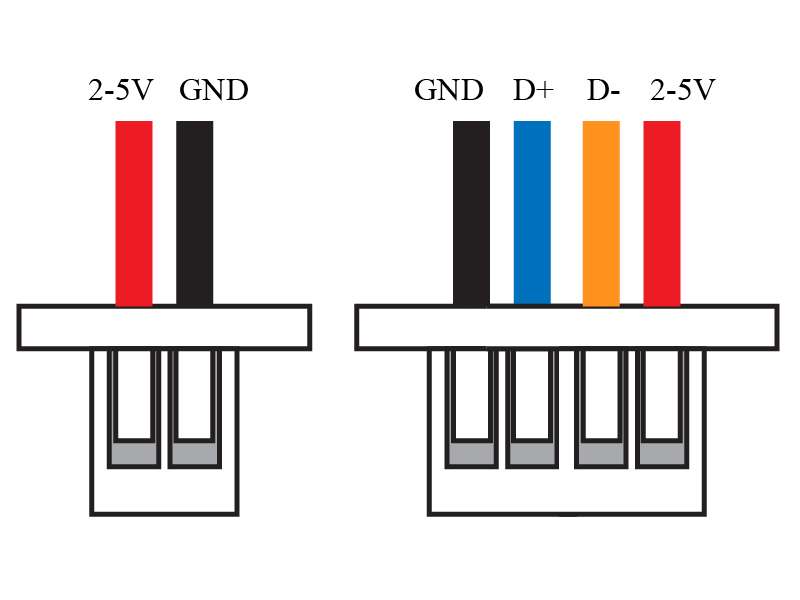
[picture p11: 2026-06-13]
docs/images/WIrelessEphys_Github_6_Connectors.jpg

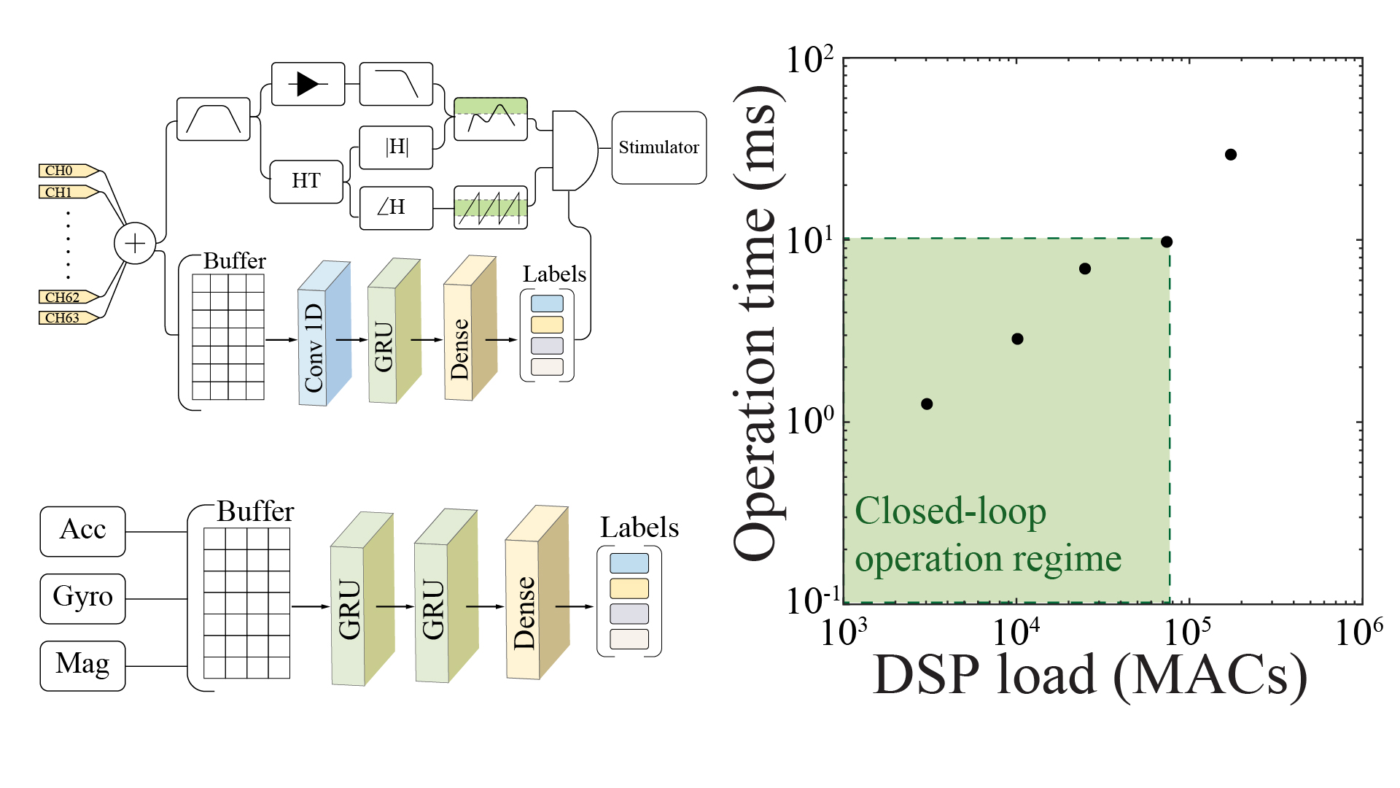
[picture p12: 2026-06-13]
docs/images/WIrelessEphys_Github_7_TinyML.jpg

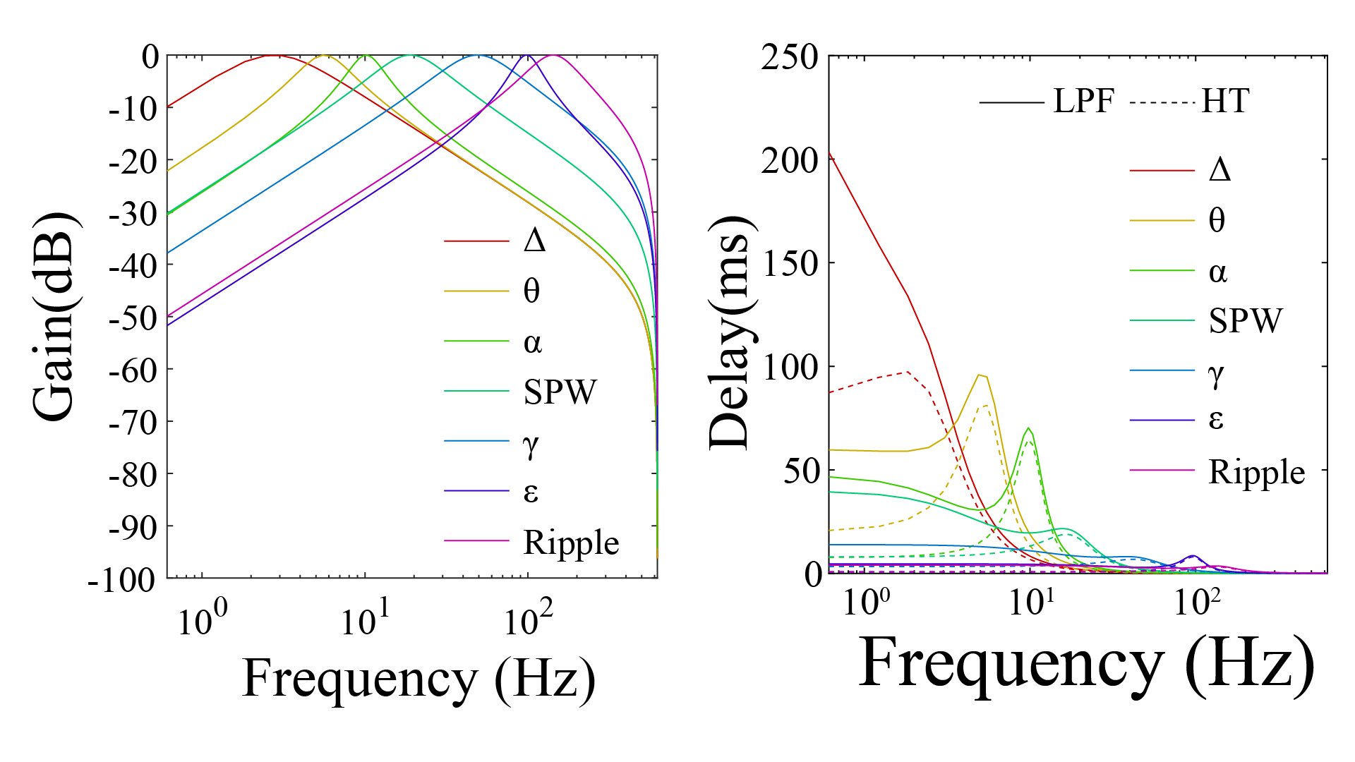
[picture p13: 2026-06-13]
docs/images/WIrelessEphys_Github_3_filterParams.jpg

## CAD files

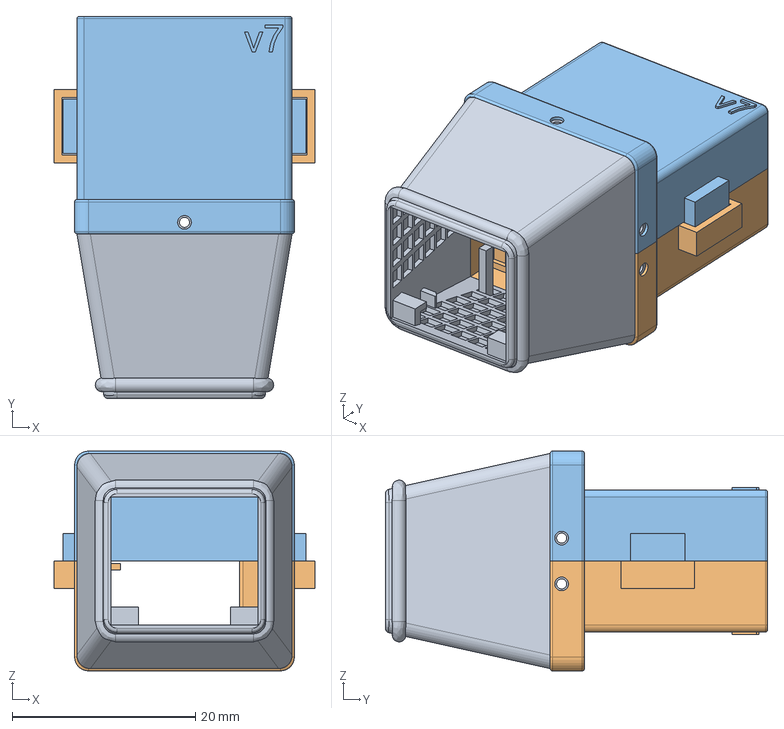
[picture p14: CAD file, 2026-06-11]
3Dprint/CambridgeNT_Probe/WILDAssemblyVertical.stp
28.5 x 41.8 x 24.0 mm
Walls

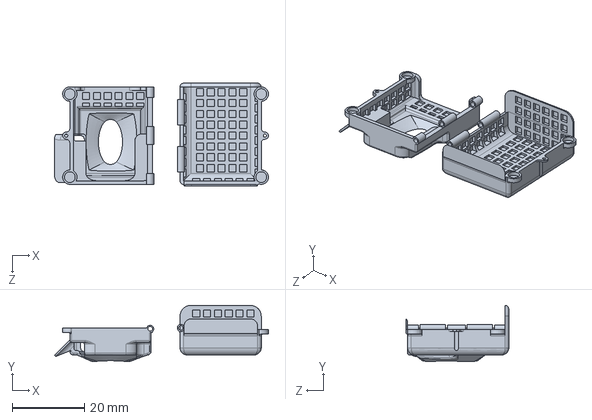
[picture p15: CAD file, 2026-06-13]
3Dprint/MouseCase/Wild_Case.SLDPRT
59.2 x 15.6 x 28.4 mm

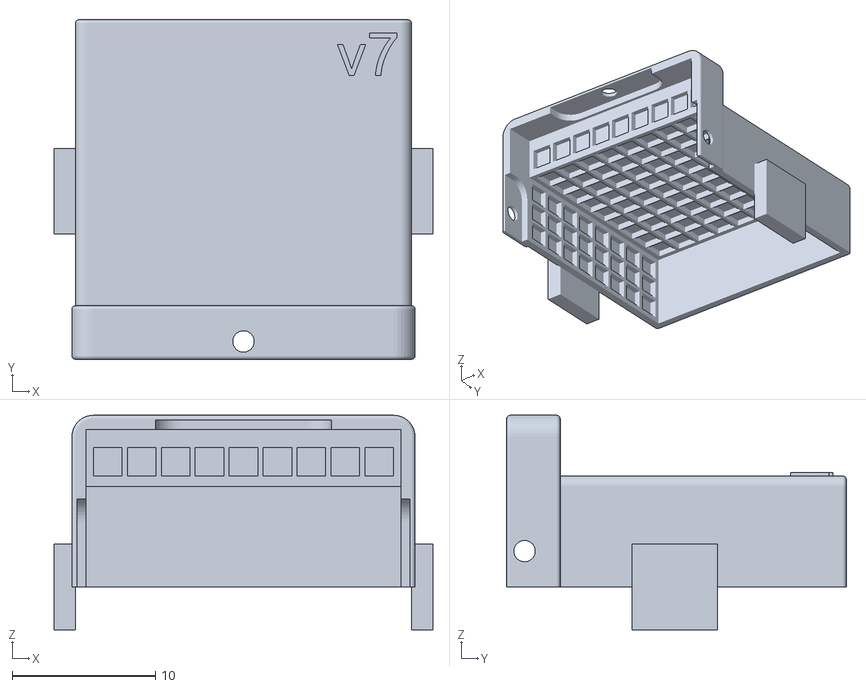
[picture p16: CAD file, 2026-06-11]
3Dprint/CambridgeNT_Probe/Left_v7.stl
26.5 x 23.8 x 15.0

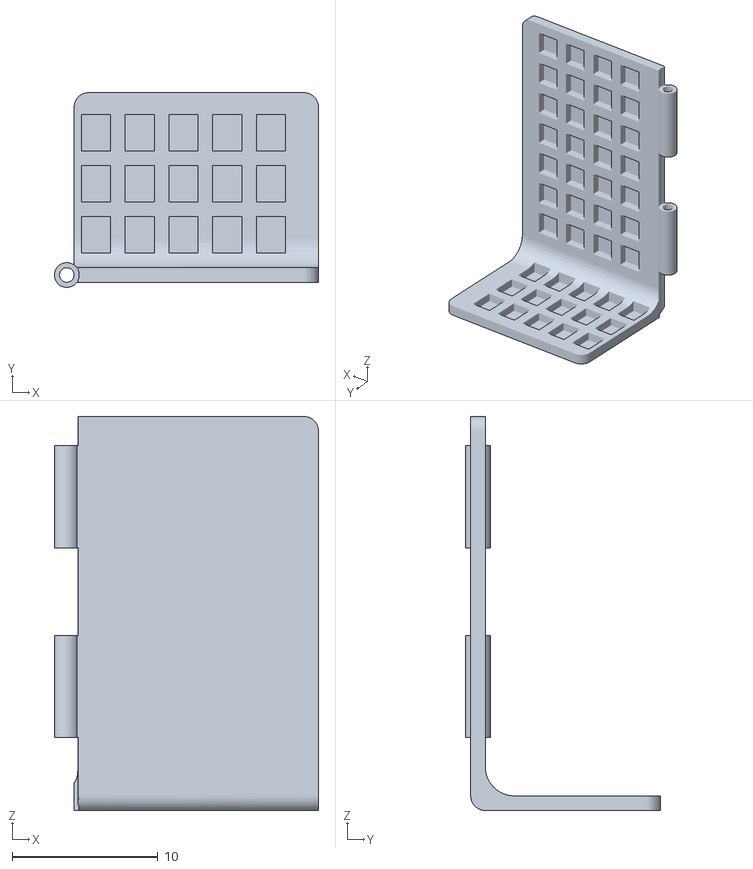
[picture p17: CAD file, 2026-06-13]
3Dprint/MouseCase/WILD_TopCover.STL
18.1 x 13.3 x 27.0

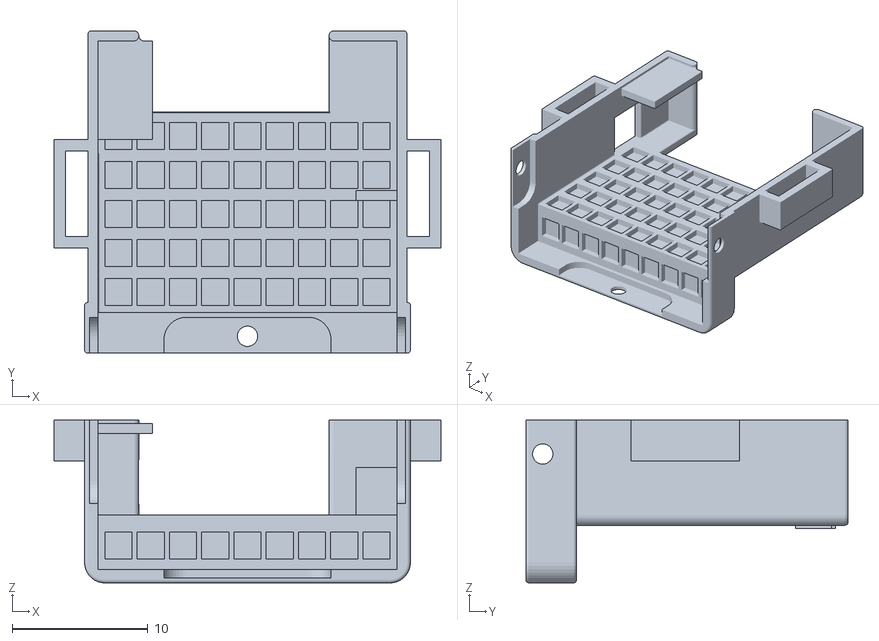
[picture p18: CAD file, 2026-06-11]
3Dprint/CambridgeNT_Probe/Right_v7.stl
28.5 x 23.8 x 12.0

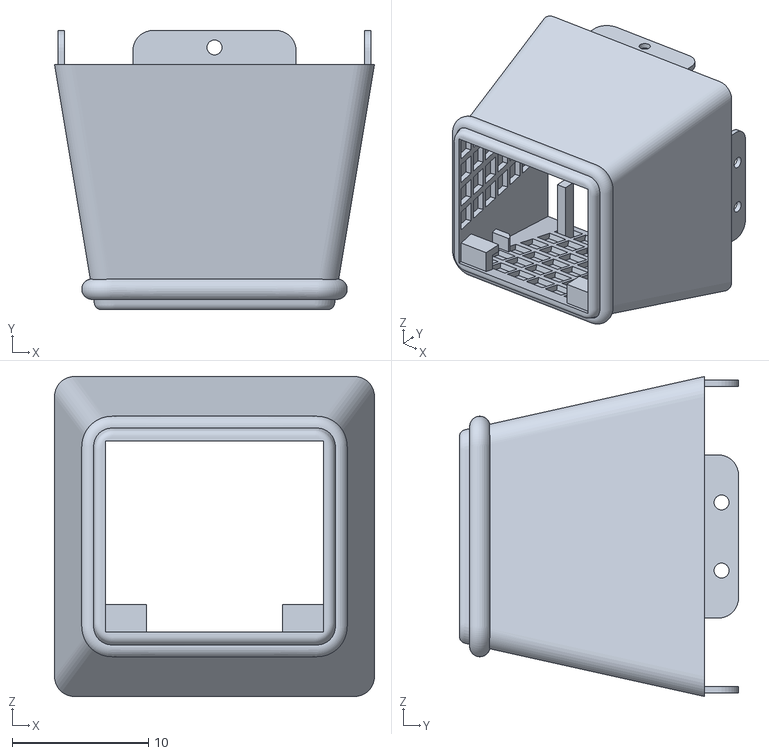
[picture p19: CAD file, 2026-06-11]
3Dprint/CambridgeNT_Probe/Cone_v7.stl
23.5 x 20.5 x 23.5

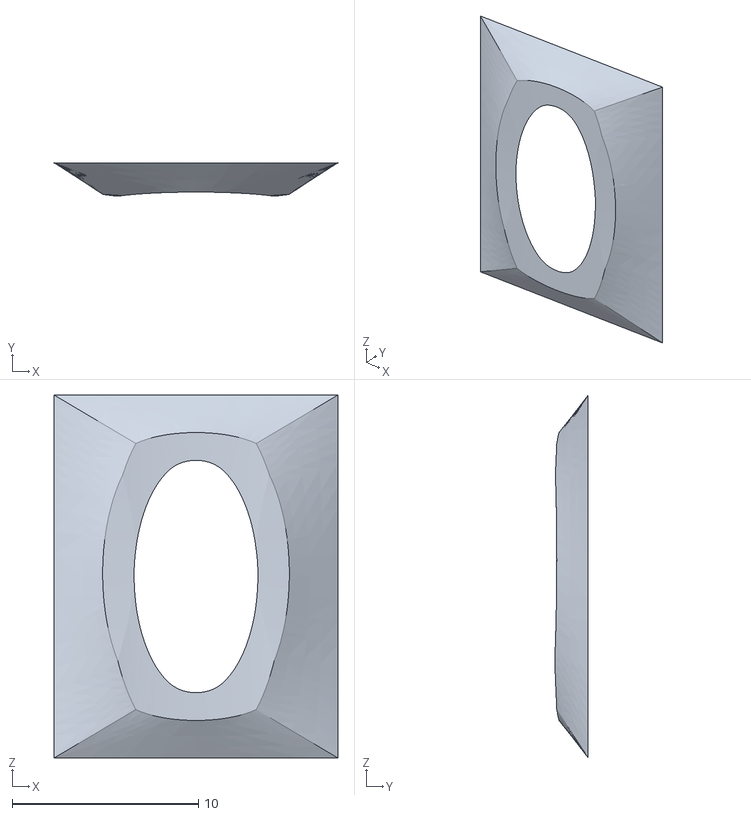
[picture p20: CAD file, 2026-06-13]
3Dprint/MouseCase/WILD_Baseplate.STL
15.2 x 1.80 x 19.5

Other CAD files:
3Dprint/MouseCase/WILD_Baseplate_Camera.STL
3Dprint/CambridgeNT_Probe/WILDAssemblyVertical.f3d
3Dprint/MouseCase/WILD_Case.f3d

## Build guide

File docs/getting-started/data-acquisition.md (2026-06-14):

# Data Acquisition

WILD_console is the main operator interface for BLE connection, synchronization, recording configuration, low-bandwidth live preview, closed-loop control, and SD-card export.

WILD is a local-storage neurologger: high-bandwidth neural and multimodal data are written to the microSD card on the device. BLE supports setup, timing calibration, status messages, command delivery, and selected preview signals.

The current public workflow uses WILD_console on Windows for BLE control. An iOS-based WILD controller app is in development for device discovery, connection, synchronization support, status checks, and low-bandwidth control. The iOS workflow is expected to provide more consistent BLE performance than typical PC BLE adapters, while full-resolution recordings will still be recovered from the device microSD card.

The WILD device does not need continuous full-bandwidth wireless streaming to preserve the recording. Keep BLE connected when the session needs online preview, parameter changes, or live commands; otherwise, use BLE for setup and timing coordination, then recover the full dataset from the microSD card.

!!! tip "First-session scope"
    For the first dry run, use only the minimum path needed to connect, record, stop, and export. Leave closed-loop, camera, stimulation, GPIO, and advanced parameter panels unchanged until the basic local-storage workflow is confirmed.

## First-Pass Button Path

For a basic dry run, only a small part of WILD_console is needed. The closed-loop, camera, stimulation, GPIO, and advanced parameter panels can stay unchanged until the device is already connecting, synchronizing, recording, and exporting reliably.

The online and live figures below are runtime screenshots from WILD_console during hardware sessions. Some window-title or device-list strings may still show older internal labels; the public documentation uses the WILD name consistently.

<div class="wild-operator-path">
  <div class="wild-operator-step">
    <span class="wild-button-label">Online tab</span>
    <p><strong>Connect to the device.</strong> Work in the Online tab for BLE discovery, synchronization, preview, and recording control.</p>
  </div>
  <div class="wild-operator-step">
    <span class="wild-button-label">Rescan</span>
    <p><strong>Find nearby WILD devices.</strong> If the device is not listed, rescan after confirming power, battery, and BLE status.</p>
  </div>
  <div class="wild-operator-step">
    <span class="wild-button-label">Device List</span>
    <p><strong>Select the target logger.</strong> The selected row updates device information, available space, and connection state.</p>
  </div>
  <div class="wild-operator-step">
    <span class="wild-button-label primary">Connect</span>
    <p><strong>Open the BLE session.</strong> Wait for the device state and synchronization labels before starting a recording.</p>
  </div>
  <div class="wild-operator-step">
    <span class="wild-button-label primary">Recording Start</span>
    <p><strong>Start local logging.</strong> Full-resolution data are written to the device microSD card, not streamed continuously over BLE.</p>
  </div>
  <div class="wild-operator-step">
    <span class="wild-button-label">Recording Stop</span>
    <p><strong>Close the recording cleanly.</strong> Stop before removing power or taking out the microSD card.</p>
  </div>
  <div class="wild-operator-step">
    <span class="wild-button-label">Offline tab</span>
    <p><strong>Move to export after recording.</strong> Insert the microSD card into the PC and use the Offline tab for SD-card download.</p>
  </div>
  <div class="wild-operator-step">
    <span class="wild-button-label primary">Save to Disk</span>
    <p><strong>Export the recording folder.</strong> WILD_console decodes the SD-card recording into the public analysis files.</p>
  </div>
</div>

<p class="wild-operator-note">
  First-session rule: ignore <span class="wild-button-label muted">Closed-loop</span>, <span class="wild-button-label muted">Camera</span>, <span class="wild-button-label muted">Advanced</span>, and parameter panels until a simple recording can be started, stopped, and exported.
</p>

WILD_console runtime screenshot during connected acquisition

## Connect

1. Launch `WILD_console.exe`.
2. Click <span class="wild-button-label">Rescan</span> if the device is not listed.
3. Select the WILD device from <span class="wild-button-label">Device List</span>.
4. Click <span class="wild-button-label primary">Connect</span> and wait for device-state and synchronization updates.
5. Confirm the TX/RX indicators update. If BLE connects but synchronization does not start, check the microSD card and timing setup first.

**Expected signs of success**

- The device appears in the list after rescan.
- The selected row updates device information.
- Connect succeeds without repeated disconnect loops.
- Status labels move past simple discovery into an active connected state.

## Record

1. Confirm the expected sampling speed and channels.
2. Leave closed-loop and camera settings unchanged unless the experiment needs them.
3. Use `Wait for start` only when coordinating multiple WILD_console instances.
4. Click <span class="wild-button-label primary">Recording Start</span> to begin local logging on the device.
5. Click <span class="wild-button-label">Recording Stop</span> when the experiment is complete.

**Expected signs of success**

- Recording starts without a parameter or storage error.
- The session duration advances normally.
- The device remains stable through stop.
- Exported files are longer than a trivial test header and have plausible file sizes.

## Field Validation

Before a field or multi-animal session, run a short dry run with every WILD device that will be used.

1. Connect each device and confirm it reaches the synchronized state.
2. Start and stop a short local recording on each device.
3. Export the SD card immediately and confirm expected duration, file size, and representative channels.
4. Use the release image specified for the experiment and hardware revision.
5. For multi-device sessions, repeat the dry run with the planned start order, external I/O wiring, and any camera or TTL sync source attached.

A connected or synchronized GUI state is not, by itself, proof that data were written for the full intended duration. Treat unexpectedly short files, stalled file-size indicators, unstable offsets, frame drops, or missing channels as blockers before animal recordings.

## Live Display

The real-time view supports selected neural previews, auxiliary signals, IMU and DSP states, stimulation triggers, and threshold overlays. See [Live Visualization](../software/live-visualization.md) for the runtime preview screenshot and display controls.

Disable preview to save power and BLE bandwidth when live monitoring is not needed. Recover full-resolution recording data from the microSD card after the session.

## Download

Insert the SD card and click <span class="wild-button-label primary">Save to Disk</span>. WILD_console exports recordings into timestamped folders with neural, auxiliary, ADC, camera, metadata, and parameter files.

**Expected signs of success**

- Export finishes without stopping at the first folder.
- Core files appear in the export folder: `amplifier.dat`, `analogin.dat`, `CE_params.bin`.
- `time.dat` and `info.rhd` are generated by the documented preprocessing path.
- Optional `adc.dat` and `misc.dat` appear only when audio or camera were enabled.

<p class="wild-operator-note">
  Normal export does not require the red maintenance buttons. <span class="wild-button-label warning">Quick Format</span> is only for preparing a known empty card, and release-image maintenance is outside the routine recording path.
</p>

WILD_console runtime screenshot of the offline export workflow

## Common Blockers

| Symptom | First check |
| --- | --- |
| Device not listed after rescan | Battery, power, BLE discoverability, and whether the expected release image is installed. |
| BLE connects but synchronization never settles | microSD presence, timing wiring, and whether the session is waiting on external sync conditions. |
| Recording starts but export is unexpectedly short | Stop sequence, SD-card write stability, battery stability, and whether the device remained powered through the run. |
| Export folder is missing expected files | Recording mode, whether audio or camera were enabled, and whether preprocessing was run after export. |
| Preview is unstable | Treat preview as optional; confirm local recording first, then revisit BLE preview bandwidth or adapter quality. |

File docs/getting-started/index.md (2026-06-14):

# Getting Started

A prepared WILD device moves from hardware checks to acquisition and analysis through three main steps.

<div class="wild-grid two">
  <div class="wild-card">
    <h3>1. Hardware setup</h3>
    <p>WILD device, connector, microSD, battery, probe or sensor cabling, and release-image checks before the first recording.</p>
  </div>
  <div class="wild-card">
    <h3>2. Data acquisition</h3>
    <p>WILD_console provides BLE discovery, synchronization, recording configuration, closed-loop control, and data export.</p>
  </div>
  <div class="wild-card">
    <h3>3. Data analysis</h3>
    <p>Compatible headers, timing files, decoded camera streams, processed IMU data, and spike-sorting inputs.</p>
  </div>
</div>

## Before You Begin

- Windows 10 or later for WILD_console.
- Bluetooth 4.0 or later for BLE control.
- A tested microSD card installed in the WILD device. Use Samsung EVO series or tested Lexar cards for first recordings; some SanDisk cards may be unreliable.
- A battery that can boot the WILD device and sustain the planned recording mode.

## Repository Assets

| Asset | Location |
| --- | --- |
| Prebuilt device images | [Latest GitHub release](https://github.com/ayalab1/Neurologger/releases/latest) |
| WILD_console installers | [Latest GitHub release](https://github.com/ayalab1/Neurologger/releases/latest) |
| PCB fabrication files | [PCB](https://github.com/ayalab1/Neurologger/tree/main/PCB) |
| 3D-print files | [3Dprint](https://github.com/ayalab1/Neurologger/tree/main/3Dprint) |
| MATLAB and Python analysis scripts | [Code](https://github.com/ayalab1/Neurologger/tree/main/Code) |

!!! tip "Recommended first path"
    The recommended first-device path is Hardware Setup, Data Acquisition, then Data Analysis. The WILD device SD card, battery, release image, and boot state provide the baseline for troubleshooting acquisition.

## First Successful Dry Run

**Goal:** complete a short bench recording and confirm that the public export and analysis path works before changing advanced settings.

**Minimum output folder:**

- `amplifier.dat`
- `analogin.dat`
- `time.dat`
- `info.rhd`
- `CE_params.bin`

**Optional outputs, depending on mode:**

- `adc.dat` for audio workflows
- `misc.dat` for camera workflows
- `device_event.*.evt` files after MATLAB preprocessing
- `IMU.mat` after IMU processing

**Success criteria:**

1. The WILD device is discovered and connected in WILD_console.
2. A short recording starts and stops cleanly.
3. SD-card export completes without missing-core-file errors.
4. The exported folder contains the expected files for the recording mode used.
5. MATLAB or Python post-processing runs without requiring manual file repair.

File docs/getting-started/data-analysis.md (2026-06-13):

# Data Analysis

The repository includes MATLAB and Python scripts for converting WILD recordings into analysis-ready files.

## Standard Post-processing

1. Export data from WILD_console.
2. Run `WILD_PreProcess.m` to generate corrected headers and timing files.
3. Run `WILD_processIMU.m` for IMU processing.
4. Run `WILD_VideoDecodewAudio.py` or the folder variants for camera recordings.
5. Prepare spike-sorting inputs from `amplifier.dat`.

## Script Locations

| Task | Script |
| --- | --- |
| Header and time correction | [`WILD_PreProcess.m`](https://github.com/ayalab1/Neurologger/blob/main/Code/WILD_PreProcess.m) |
| IMU processing | [`WILD_processIMU.m`](https://github.com/ayalab1/Neurologger/blob/main/Code/WILD_processIMU.m) |
| Camera decode with audio | [`WILD_VideoDecodewAudio.py`](https://github.com/ayalab1/Neurologger/blob/main/Code/WILD_VideoDecodewAudio.py) |
| Intan header generation | [`WILD_genIntanHeader.m`](https://github.com/ayalab1/Neurologger/blob/main/Code/WILD_genIntanHeader.m) |

!!! note
    Keep raw SD exports unchanged. Run conversion scripts into a separate analysis folder so the original recording can be reprocessed if metadata or analysis settings change.

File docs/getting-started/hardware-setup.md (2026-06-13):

# Hardware Setup

This checklist covers the physical preparation before connecting WILD to software.

## Device and Connectors

Connector images identify the stimulation, auxiliary, sensor, sync, and battery interfaces before board power-up.

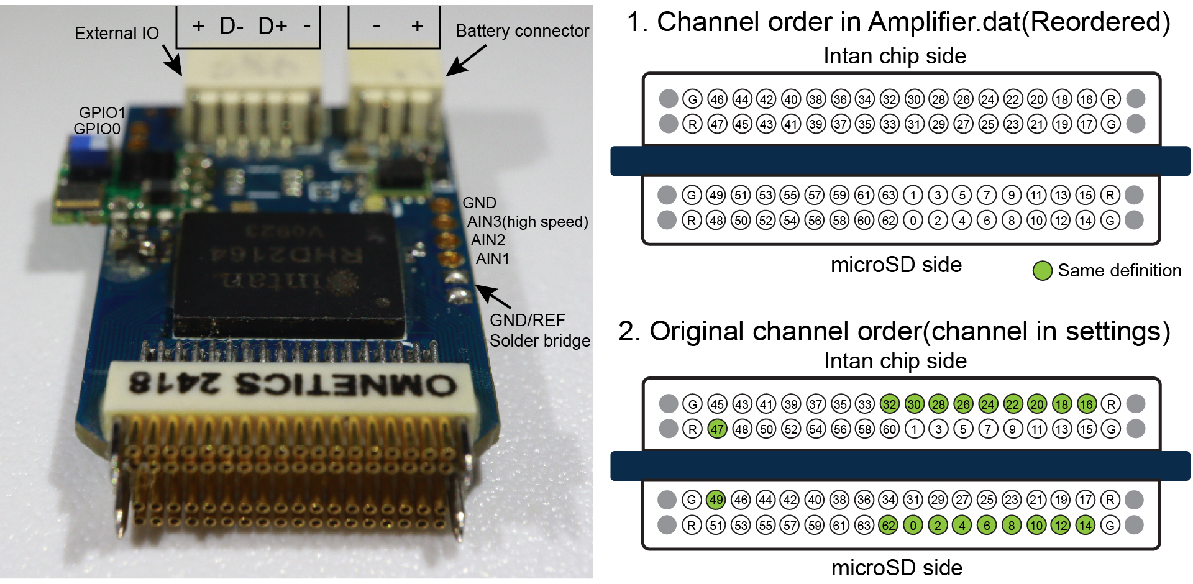
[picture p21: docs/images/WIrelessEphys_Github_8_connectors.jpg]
WILD connector overview


The WILD device uses these connectors to keep acquisition, storage, wireless control, synchronization, and optional stimulation in a compact head-mounted unit. Before powering the device, confirm which interfaces are actually part of the planned session.

## Preparation Checklist

1. Inspect the PCB and connectors for visible damage.
2. Confirm battery polarity on the JST-SH connector.
3. Insert a tested microSD card.
4. Confirm the recording probe or flexible-probe connection.
5. Confirm the stimulation output, IMU, microphone, camera, and external sync connections needed for the experiment.
6. Confirm the device is running the expected released device image for the experiment.

## microSD Card

Format the card from WILD_console before recording. The microSD card affects both reliability and power draw.

microSD power comparison

Battery and SD guidance are part of the experimental protocol, not optional accessory setup.

Battery examples

## Released Device Image

Public setup documentation is based on prebuilt WILD release images. The release image is matched to the hardware revision and experimental configuration, with the release tag and image filename kept in dataset metadata.

Release images are distributed through the [latest GitHub release](https://github.com/ayalab1/Neurologger/releases/latest). Follow the release notes for the specific image used in the experiment.

Treat the released device image as part of the hardware setup record. The WILD device, WILD_console version, SD card, battery, and analysis scripts should all be traceable to the dataset.

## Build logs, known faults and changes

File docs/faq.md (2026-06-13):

# FAQ

## Is WILD a replacement for wired acquisition?

WILD is designed for wireless and naturalistic experiments where tethered acquisition is limiting. The correct choice depends on channel count, runtime, signal quality, synchronization, and behavioral constraints.

## Is WILD a BLE telemetry system?

No. WILD is primarily a local-storage neurologger. High-bandwidth neural and multimodal data are recorded to the device microSD card. BLE is used for discovery, configuration, synchronization support, status, selected low-bandwidth preview, and control commands.

## Will WILD have an iOS controller?

An iOS-based WILD controller app is in development for device discovery, BLE connection, synchronization support, status checks, and low-bandwidth commands. It is expected to provide more consistent wireless-control performance than typical PC BLE adapters, but full-resolution recordings will still be stored locally on the device microSD card.

## What is the current recording scale?

The current open-source workflow is the 64-channel WILD system. Neuropixels-compatible and active-SPI-probe variants are higher-performance research targets and are separate from the current public release.

## How do I install the PC software?

The latest installer is available from the [latest GitHub release](https://github.com/ayalab1/Neurologger/releases/latest), with setup details in the acquisition guide.

## BLE connects, but recording does not start

The microSD card is the first item to verify. SD format and card compatibility are common causes when BLE connects but synchronization does not begin.

## Does WILD support TinyML?

WILD supports online inference of curated, experiment-specific models through validated release images. Runtime generic model loading is not part of the stable public workflow yet.

## How do I cite WILD?

The under-review platform manuscript entry is listed on the [Publications](publications/index.md) page. Reproducible methods include the WILD hardware revision, release image, WILD_console version, and analysis-script version.

## Where do new diagrams go?

Source diagrams are best kept editable where possible, with web-ready images exported into `docs/images/`. For readable architecture diagrams, Mermaid in Markdown is preferred.

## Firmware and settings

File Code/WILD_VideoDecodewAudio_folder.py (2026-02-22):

import cv2
import numpy as np
import os
from tkinter import Tk
from tkinter import filedialog
import wave
import scipy.ndimage
from scipy.signal import butter, filtfilt
from moviepy import VideoFileClip, AudioFileClip
import lameenc
import librosa


def readmulti_frank(file, byte_offset, byte_length, dtype):
    """ Function to read binary data from file """
    with open(file, 'rb') as f:
        f.seek(byte_offset)
        data = f.read(byte_length)
    return np.frombuffer(data, dtype=dtype)


def save_binary_audio_to_wav(audio_file, sample_rate, output_path):
    with open(audio_file, "rb") as f:
        audio_binary = f.read()

    audio_array = np.frombuffer(audio_binary, dtype=np.uint16)
    audio_array = (audio_array - 32768).astype(np.int16)
    print(f"Audio file sps: {audio_array.shape[0]}, fs: {sample_rate},duration: {audio_array.shape[0]/sample_rate}")

    nyquist = 0.5 * sample_rate
    normal_cutoff = 1 / nyquist
    b, a = butter(N=2, Wn=normal_cutoff, btype='high', analog=False)
    audio_array = filtfilt(b, a, audio_array).astype(np.int16)

    with wave.open(output_path, 'wb') as wav_file:
        wav_file.setnchannels(1)
        wav_file.setsampwidth(2)
        wav_file.setframerate(sample_rate)
        print(f"Audio file samples after preprocessing:{audio_array.shape[0]}")
        wav_file.writeframesraw(audio_array.tobytes())


def save_binary_audio_to_mp3(audio_file, sample_rate, output_path):
    with open(audio_file, "rb") as f:
        audio_binary = f.read()

    audio_array = np.frombuffer(audio_binary, dtype=np.uint16)
    audio_array = (audio_array - 32768).astype(np.float32)

    print(f"Audio file sps: {audio_array.shape[0]}, fs: {sample_rate},duration: {audio_array.shape[0]/sample_rate}")

    nyquist = 0.5 * sample_rate
    normal_cutoff = 20000 / nyquist
    b, a = butter(N=2, Wn=normal_cutoff, btype="high", analog=False)
    filtered_audio = filtfilt(b, a, audio_array)

    filtered_audio = librosa.effects.pitch_shift(filtered_audio, sr=sample_rate, n_steps=-24)
    filtered_audio = librosa.resample(filtered_audio, orig_sr=sample_rate, target_sr=48000)
    sample_rate = 48000

    filtered_audio = np.clip(filtered_audio, -32768, 32767).astype(np.int16)

    encoder = lameenc.Encoder()
    encoder.set_bit_rate(384)
    encoder.set_in_sample_rate(sample_rate)
    encoder.set_channels(1)
    encoder.set_quality(0)

    mp3_data = encoder.encode(filtered_audio.tobytes()) + encoder.flush()

    with open(output_path, "wb") as mp3_file:
        mp3_file.write(mp3_data)

    print(f"Audio saved to {output_path}")


def adjust_brightness_contrast(image, target_brightness=128):
    current_brightness = np.mean(image)
    brightness_factor = target_brightness / max(current_brightness, 1e-6)
    adjusted_img = np.clip(image * brightness_factor, 0, 255).astype(np.uint8)
    return adjusted_img

def compute_global_percentiles(file, frames, byte_per_img,
                               width, height,
                               sample_frames=200,
                               percentile_low=1,
                               percentile_high=99):

    import cv2
    import numpy as np

    accum = [[], [], []]

    with open(file, "rb") as f:

        for idx in range(min(sample_frames, frames)):

            f.seek(idx * byte_per_img)
            raw = np.frombuffer(f.read(byte_per_img), dtype=np.uint8)

            img = np.reshape(raw[:320 * 492], (-1, 492)).T
            img = img[12:, :].T.flatten().astype(np.uint16)

            unpacked = np.zeros(len(img) * 2 // 3, dtype=np.uint16)
            unpacked[0::2] = ((img[0::3] & 0x7F) << 3) | ((img[1::3] & 0xE0) >> 5)
            unpacked[1::2] = ((img[1::3] & 0x07) << 7) | ((img[2::3] & 0xFE) >> 1)

            unpacked = np.reshape(unpacked, (-1, 320))
            unpacked = unpacked * 64
            unpacked = np.rot90(unpacked, 2)

            rgb = cv2.demosaicing(unpacked, cv2.COLOR_BAYER_RG2RGB_EA)

            for c in range(3):
                accum[c].append(rgb[:,:,c].flatten())

    global_low = []
    global_high = []

    for c in range(3):
        vals = np.concatenate(accum[c])
        global_low.append(np.percentile(vals, percentile_low))
        global_high.append(np.percentile(vals, percentile_high))

    return global_low, global_high
def WILD_Camera_Decode_HQ(file=None,
                          fps=16,
                          output_codec="hevc",
                          percentile_low=1,
                          percentile_high=99,
                          sample_frames_for_stats=200):

    import os
    import cv2
    import numpy as np
    import subprocess
    from tkinter import Tk, filedialog

    # -------------------------------
    # File selection
    # -------------------------------
    if file is None:
        root = Tk()
        root.withdraw()
        file = filedialog.askopenfilename(
            title="Select WILD video file",
            filetypes=[("WILD video file", "*misc.dat")]
        )
        if not file:
            return

    if not os.path.exists(file):
        raise FileNotFoundError("Video file not found")

    file_size = os.path.getsize(file)
    if file_size == 0:
        print("Skipping empty file.")
        return

    width = 320
    height = 320
    byte_per_img = 320 * 500
    frames = file_size // byte_per_img

    if frames == 0:
        print("No valid frames.")
        return

    print(f"Total frames: {frames}")

    parent_dir = os.path.dirname(file)
    base_name = os.path.basename(parent_dir)

    # -------------------------------
    # Audio
    # -------------------------------
    audio_wav = file.replace("misc.dat", "adc.wav")
    use_audio = os.path.exists(audio_wav)

    # -------------------------------
    # Compute global percentile scaling
    # -------------------------------
    print("Computing global percentiles...")

    accum = [[], [], []]

    with open(file, "rb") as f:

        for _ in range(min(sample_frames_for_stats, frames)):

            raw = np.frombuffer(f.read(byte_per_img), dtype=np.uint8)

            img = raw[:320 * 492].reshape(-1, 492).T
            img = img[12:, :].T.flatten().astype(np.uint16)

            unpacked = np.empty(len(img) * 2 // 3, dtype=np.uint16)
            unpacked[0::2] = ((img[0::3] & 0x7F) << 3) | ((img[1::3] & 0xE0) >> 5)
            unpacked[1::2] = ((img[1::3] & 0x07) << 7) | ((img[2::3] & 0xFE) >> 1)

            unpacked = unpacked.reshape(-1, 320)
            unpacked <<= 6
            unpacked = unpacked[::-1, ::-1]

            rgb = cv2.demosaicing(unpacked, cv2.COLOR_BAYER_RG2RGB_EA)

            for c in range(3):
                accum[c].append(rgb[:, :, c].ravel())

    global_low = np.array([
        np.percentile(np.concatenate(accum[c]), percentile_low)
        for c in range(3)
    ], dtype=np.float32).reshape(1, 1, 3)

    global_high = np.array([
        np.percentile(np.concatenate(accum[c]), percentile_high)
        for c in range(3)
    ], dtype=np.float32).reshape(1, 1, 3)

    global_range = np.maximum(global_high - global_low, 1e-6)

    print("Global scaling computed.")

    # -------------------------------
    # Output configuration
    # -------------------------------
    if output_codec == "ffv1":

        output_file = os.path.join(parent_dir, f"{base_name}_LOSSLESS.mkv")

        ffmpeg_cmd = [
            "ffmpeg", "-y",
            "-f", "rawvideo",
            "-pix_fmt", "rgb48le",
            "-s", f"{width}x{height}",
            "-r", str(fps),
            "-i", "pipe:0",
        ]

        if use_audio:
            ffmpeg_cmd += ["-i", audio_wav]

        ffmpeg_cmd += ["-c:v", "ffv1", "-level", "3"]

        if use_audio:
            ffmpeg_cmd += [
                "-c:a", "flac",
                "-map", "0:v:0",
                "-map", "1:a:0"
            ]

        ffmpeg_cmd.append(output_file)

    elif output_codec == "hevc":

        output_file = os.path.join(parent_dir, f"{base_name}_HEVC10bit.mp4")

        ffmpeg_cmd = [
            "ffmpeg", "-y",
            "-f", "rawvideo",
            "-pix_fmt", "rgb48le",
            "-s", f"{width}x{height}",
            "-r", str(fps),
            "-i", "pipe:0",
        ]

        if use_audio:
            ffmpeg_cmd += ["-i", audio_wav]

        ffmpeg_cmd += [
            "-c:v", "hevc_nvenc",
            "-preset", "p5",
            "-rc", "vbr",
            "-cq", "14",
            "-pix_fmt", "p010le",
        ]

        if use_audio:
            ffmpeg_cmd += [
                "-c:a", "aac",
                "-b:a", "192k",
                "-ar", "48000",
                "-map", "0:v:0",
                "-map", "1:a:0"
            ]

        ffmpeg_cmd.append(output_file)

    else:
        raise ValueError("output_codec must be 'ffv1' or 'hevc'")

    # -------------------------------
    # Launch encoder
    # -------------------------------
    process = subprocess.Popen(ffmpeg_cmd, stdin=subprocess.PIPE)

    # -------------------------------
    # Frame processing loop
    # -------------------------------
    with open(file, "rb") as f:

        for idx in range(frames):

            if idx % 50 == 0:
                print(f"Processing {idx}/{frames}")

            raw = np.frombuffer(f.read(byte_per_img), dtype=np.uint8)

            img = raw[:320 * 492].reshape(-1, 492).T
            img = img[12:, :].T.flatten().astype(np.uint16)

            unpacked = np.empty(len(img) * 2 // 3, dtype=np.uint16)
            unpacked[0::2] = ((img[0::3] & 0x7F) << 3) | ((img[1::3] & 0xE0) >> 5)
            unpacked[1::2] = ((img[1::3] & 0x07) << 7) | ((img[2::3] & 0xFE) >> 1)

            unpacked = unpacked.reshape(-1, 320)
            unpacked <<= 6
            unpacked = unpacked[::-1, ::-1]

            rgb = cv2.demosaicing(unpacked, cv2.COLOR_BAYER_RG2RGB_EA)
            rgb = rgb.astype(np.float32)

            rgb = (rgb - global_low) / global_range
            np.clip(rgb, 0, 1, out=rgb)

            rgb_16 = (rgb * 65535).astype(np.uint16)

            process.stdin.write(rgb_16.tobytes())

    process.stdin.close()
    process.wait()

    print("Done.")
    print("Output saved to:", output_file)


def WILD_Camera_Decode_HQ_(file=None,
                          fps=16,
                          output_codec="hevc",
                          percentile_low=1,
                          percentile_high=99):

    import os
    import cv2
    import numpy as np
    import subprocess
    from tkinter import Tk, filedialog

    # --------------------------------------------------
    # File selection
    # --------------------------------------------------
    if file is None:
        root = Tk()
        root.withdraw()
        file = filedialog.askopenfilename(
            title="Select WILD video file",
            filetypes=[("WILD video file", "*misc.dat")]
        )
        if not file:
            print("No file selected.")
            return

    if not os.path.exists(file):
        raise FileNotFoundError("Video file not found")

    # --------------------------------------------------
    # Skip empty file
    # --------------------------------------------------
    file_size = os.path.getsize(file)
    parent_dir = os.path.dirname(file)
    last_folder = os.path.basename(parent_dir)
    base_name = f"{last_folder}_misc"
    
    audio_wav = file.replace("misc.dat", "adc.wav")
    use_audio = os.path.exists(audio_wav)

    if file_size == 0:
        print(f"Skipping empty file: {file}")
        return

    width = 320
    height = 320
    byte_per_img = 320 * 500

    frames = file_size // byte_per_img

    if frames == 0:
        print(f"Skipping file with 0 valid frames: {file}")
        return

    print(f"Total frames: {frames}")

    # --------------------------------------------------
    # Output config
    # --------------------------------------------------
    if output_codec == "ffv1":

        output_file = os.path.join(parent_dir, f"{base_name}_LOSSLESS.mkv")

        ffmpeg_cmd = [
            "ffmpeg",
            "-y",

            # ---- video input (pipe) ----
            "-f", "rawvideo",
            "-pix_fmt", "rgb48le",
            "-s", f"{width}x{height}",
            "-r", str(fps),
            "-i", "pipe:0",
        ]

        if use_audio:
            ffmpeg_cmd += ["-i", audio_wav]

        ffmpeg_cmd += [
            "-c:v", "ffv1",
            "-level", "3",
        ]

        if use_audio:
            ffmpeg_cmd += [
                "-c:a", "flac",     # lossless audio
                "-map", "0:v:0",
                "-map", "1:a:0",
            ]

        ffmpeg_cmd.append(output_file)

    elif output_codec == "hevc":

        output_file = os.path.join(parent_dir, f"{base_name}_HEVC10bit.mp4")

        ffmpeg_cmd = [
            "ffmpeg",
            "-y",

            # ---- video input ----
            "-f", "rawvideo",
            "-pix_fmt", "rgb48le",
            "-s", f"{width}x{height}",
            "-r", str(fps),
            "-i", "pipe:0",
        ]

        if use_audio:
            ffmpeg_cmd += ["-i", audio_wav]

        ffmpeg_cmd += [
            "-c:v", "hevc_nvenc",
            "-rc", "constqp",
            "-qp", "12",
            "-preset", "p5",
            "-pix_fmt", "yuv444p10le",
        ]

        if use_audio:
            ffmpeg_cmd += [
                "-c:a", "aac",
                "-b:a", "192k",
                "-ar", "48000",       # ← resample to 48kHz
                "-map", "0:v:0",
                "-map", "1:a:0",
            ]

        ffmpeg_cmd.append(output_file)

    else:
        raise ValueError("output_codec must be 'ffv1' or 'hevc'")

    # --------------------------------------------------
    # Launch encoder
    # --------------------------------------------------
    process = subprocess.Popen(ffmpeg_cmd, stdin=subprocess.PIPE)

    # --------------------------------------------------
    # Frame loop
    # --------------------------------------------------
    with open(file, "rb") as f:

        for idx in range(frames):

            if idx % 50 == 0:
                print(f"Processing {idx}/{frames}")

            f.seek(idx * byte_per_img)
            raw = np.frombuffer(f.read(byte_per_img), dtype=np.uint8)

            img = np.reshape(raw[:320 * 492], (-1, 492)).T
            img = img[12:, :].T.flatten().astype(np.uint16)

            unpacked = np.zeros(len(img) * 2 // 3, dtype=np.uint16)

            unpacked[0::2] = ((img[0::3] & 0x7F) << 3) | ((img[1::3] & 0xE0) >> 5)
            unpacked[1::2] = ((img[1::3] & 0x07) << 7) | ((img[2::3] & 0xFE) >> 1)

            unpacked = np.reshape(unpacked, (-1, 320))

            unpacked = unpacked * 64
            unpacked = np.rot90(unpacked, 2)

            rgb = cv2.demosaicing(unpacked, cv2.COLOR_BAYER_RG2RGB)
            rgb = rgb.astype(np.float32)

            # Per-channel normalization
            for c in range(3):
                ch = rgb[:, :, c]
                ch_min = np.min(ch)
                ch_max = np.max(ch)
                if ch_max > ch_min:
                    ch = (ch - ch_min) / (ch_max - ch_min)
                rgb[:, :, c] = ch

            # Percentile stretch
            for c in range(3):
                ch = rgb[:, :, c]
                p_low = np.percentile(ch, percentile_low)
                p_high = np.percentile(ch, percentile_high)

                if p_high > p_low:
                    ch = (ch - p_low) / (p_high - p_low)
                    ch = np.clip(ch, 0, 1)

                rgb[:, :, c] = ch

            rgb_16 = (rgb * 65535).astype(np.uint16)

            process.stdin.write(rgb_16.tobytes())

    process.stdin.close()
    process.wait()

    print("Done.")
    print("Output saved to:", output_file)


def process_file(file_path):
    """
    Worker wrapper for parallel execution.
    Must be top-level (not nested) for Windows multiprocessing.
    Returns (file_path, success, error_message)
    """
    try:
        if not os.path.exists(file_path):
            return file_path, False, "File does not exist"

        if os.path.getsize(file_path) == 0:
            return file_path, False, "Empty file"

        WILD_Camera_Decode_HQ(file=file_path)
        return file_path, True, None

    except Exception as e:
        return file_path, False, str(e)
def process_root_folder(root_dir=None, pattern="misc.dat"):
    """
    Recursively process all *misc.dat in root_dir and subfolders.
    """
    if root_dir is None:
        tk = Tk()
        tk.withdraw()
        root_dir = filedialog.askdirectory(title="Select root folder containing WILD recordings")
        if not root_dir:
            print("No folder selected.")
            return

    targets = []
    for dirpath, _, filenames in os.walk(root_dir):
        for fn in filenames:
            if fn.endswith(pattern):
                targets.append(os.path.join(dirpath, fn))

    targets.sort()
    print(f"Found {len(targets)} files under: {root_dir}")

    ok = 0
    fail = 0
    for i, f in enumerate(targets, 1):
        print(f"\n[{i}/{len(targets)}] {f}")
        try:
            WILD_Camera_Decode_HQ(file=f)
            ok += 1
        except Exception as e:
            print(f"FAILED: {f}\n  -> {e}")
            fail += 1

    print(f"\nDone. OK={ok}, FAIL={fail}, TOTAL={len(targets)}")

if __name__ == "__main__":
    # Option A: pick a root folder interactively
    process_root_folder()

    # Option B: hardcode a root folder
    # process_root_folder(r"D:\data\WILD")

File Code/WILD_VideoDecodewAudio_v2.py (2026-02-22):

import cv2
import numpy as np
import os
from tkinter import Tk
from tkinter import filedialog
import wave
import scipy.ndimage
from scipy.signal import butter, filtfilt
from moviepy import VideoFileClip, AudioFileClip, CompositeVideoClip
import lameenc
import librosa


def readmulti_frank(file, byte_offset, byte_length, dtype):
    """ Function to read binary data from file """
    with open(file, 'rb') as f:
        f.seek(byte_offset)
        data = f.read(byte_length)
    return np.frombuffer(data, dtype=dtype)


def save_binary_audio_to_wav(audio_file, sample_rate, output_path):
    """
    Save binary audio data in uint16 format to a .wav file.
    :param audio_binary: Binary audio data in uint16 format.
    :param sample_rate: Sampling rate of the audio.
    :param output_path: Path to save the .wav file.
    """
    with open(audio_file, "rb") as f:
        # Read the entire binary file
        audio_binary = f.read()
    # Convert uint16 to int16
    audio_array = np.frombuffer(audio_binary, dtype=np.uint16)
    audio_array = (audio_array - 32768).astype(np.int16)  # Convert to signed int16
    print(f"Audio file sps: {audio_array.shape[0]}, fs: {sample_rate},duration: {audio_array.shape[0]/sample_rate}")
    #filtering
    # Design a Butterworth high-pass filter(DC-removal)
    nyquist = 0.5 * sample_rate
    normal_cutoff = 1 / nyquist
    b, a = butter(N=2, Wn=normal_cutoff, btype='high', analog=False)
    
    # Apply the filter using filtfilt for zero-phase filtering
    audio_array = filtfilt(b, a, audio_array)
    audio_array = (audio_array).astype(np.int16)  # Convert to signed int16
    with wave.open(output_path, 'wb') as wav_file:
        # Set the number of channels, sample width, and frame rate
        num_channels = 1  # Mono audio
        sample_width = 2  # 2 bytes per sample (16-bit PCM)
        wav_file.setnchannels(num_channels)
        wav_file.setsampwidth(sample_width)
        wav_file.setframerate(sample_rate)
        print(f"Audio file samples after preprocessing:{audio_array.shape[0]}")
        # Write the audio data as int16
        wav_file.writeframesraw(audio_array.tobytes())



def save_binary_audio_to_mp3(audio_file, sample_rate, output_path):
    """
    Save binary audio data in uint16 format to an MP3 file using lameenc.
    :param audio_file: Path to the input binary audio file.
    :param sample_rate: Sampling rate of the audio (Hz).
    :param output_path: Path to save the MP3 file.
    """
    with open(audio_file, "rb") as f:
        # Read the entire binary file
        audio_binary = f.read()

    # Convert uint16 to float
    audio_array = np.frombuffer(audio_binary, dtype=np.uint16)
    audio_array = (audio_array - 32768).astype(np.float32)  # Convert to float

    print(f"Audio file sps: {audio_array.shape[0]}, fs: {sample_rate},duration: {audio_array.shape[0]/sample_rate}")
    

    # Apply a Butterworth high-pass filter
    nyquist = 0.5 * sample_rate
    normal_cutoff = 20000 / nyquist  # High-pass filter with 1 Hz cutoff
    b, a = butter(N=2, Wn=normal_cutoff, btype="high", analog=False)
    filtered_audio = filtfilt(b, a, audio_array)

    # Shift pitch down by 2 octaves (factor of 4 in frequency)
    filtered_audio = librosa.effects.pitch_shift(filtered_audio, sr=sample_rate, n_steps=-24)

    # Resample from 160KHz to 48KHz
    filtered_audio = librosa.resample(filtered_audio, orig_sr=sample_rate, target_sr=48000)
    sample_rate=48000
    # Clip the audio to int16 range
    filtered_audio = np.clip(filtered_audio, -32768, 32767).astype(np.int16)

    # Encode to MP3 using lameenc
    encoder = lameenc.Encoder()
    encoder.set_bit_rate(384)  # Set bitrate (e.g., 192 kbps)
    encoder.set_in_sample_rate(sample_rate)  # Input sample rate
    encoder.set_channels(1)  # Mono
    encoder.set_quality(0)  # Higher quality (0 is best, 9 is worst)

    mp3_data = encoder.encode(filtered_audio.tobytes()) + encoder.flush()

    # Write MP3 data to file
    with open(output_path, "wb") as mp3_file:
        mp3_file.write(mp3_data)

    print(f"Audio saved to {output_path}")


def adjust_brightness_contrast(image, target_brightness=128):
    # Calculate the current brightness of the image (mean pixel value)
    current_brightness = np.mean(image)

    # Calculate the brightness scaling factor
    brightness_factor = target_brightness / current_brightness

    # Adjust brightness by scaling pixel values
    adjusted_img = np.clip(image * brightness_factor, 0, 255).astype(np.uint8)
    return adjusted_img

def auto_exposure_compensation(image):
    # Convert the image to YUV color space
    yuv_img = cv2.cvtColor(image, cv2.COLOR_RGB2YUV)

    # Apply histogram equalization to the luminance channel (Y channel)
    yuv_img[:, :, 0] = cv2.equalizeHist(yuv_img[:, :, 0])

    # Convert back to RGB color space
    result_img = cv2.cvtColor(yuv_img, cv2.COLOR_YUV2RGB)
    return result_img
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

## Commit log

2026-02-01 New logger firmware support camera + microphone + 20KHz Ephys
2026-02-05 API update, with power efficient boosted firmware
2026-02-05 Firmware update for improving power consumption and noise performance at 20KHz recording. API bug fix for manual parameter
2026-06-12 Make WILD docs more device centered
2026-06-13 updated website
    [WILD_Baseplate.STL, WILD_Baseplate_Camera.STL, WILD_Case.f3d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]
